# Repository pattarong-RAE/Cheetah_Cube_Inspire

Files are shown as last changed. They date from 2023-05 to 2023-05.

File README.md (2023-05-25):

# Cheetah_Cube_Inspire

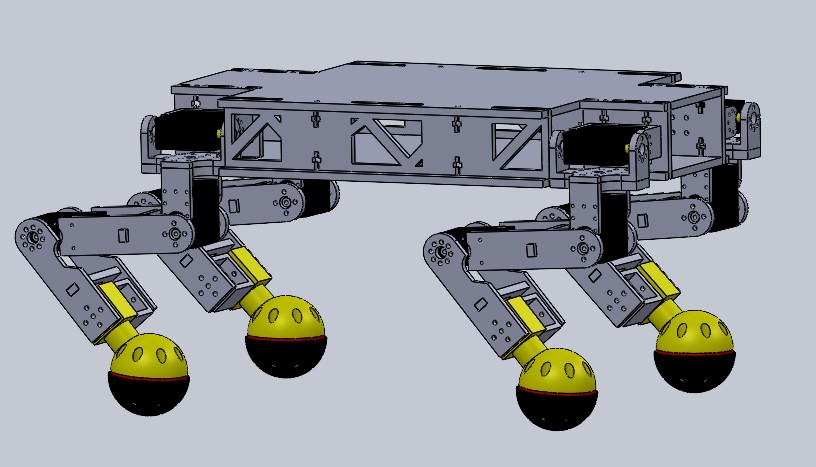
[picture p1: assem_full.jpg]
Robot


## Setup

- Install &emsp;&emsp;&emsp;&emsp;> Installation.pdf
- Setup Leg &emsp;&emsp;&nbsp;> DataRobot/datasheet/Setup_Motor.pdf

## Data

- Circuit &emsp;&emsp;&emsp;&emsp;> DataRobot/datasheet/Circuit.pdf
- Protocol &emsp;&emsp;&emsp;> DataRobot/datasheet/Protocol_send_data_Between_Ardui_and \_Python.pdf
- Set Leg robot &nbsp;&nbsp;> DataRobot/Data_set_Leg.xlsx
- Device &emsp;&emsp;&emsp;&nbsp;&nbsp;> DataRobot/DataDevice.xlsx

## Design

- Model &emsp;&emsp;&emsp;&emsp;> Model/bio
- Draw &emsp;&emsp;&emsp;&emsp;&nbsp;&nbsp;> Model/draw

## Code

- Arduino &emsp;&emsp;&emsp;&emsp;&nbsp;&nbsp;&nbsp;> Script/CheetahArduino/CheetahArduino.ino
- Python &emsp;&emsp;&emsp;&emsp;&emsp;&nbsp;> Script/main.py
- Library Python &emsp;&emsp;> Script/lib.txt
- Library Arduino &emsp;&nbsp;&nbsp;> Program/SCSServo-master

## Program

- FD-V1.9 &emsp;&emsp;&emsp;&emsp;> Program/FD-V1.9.6(20200311)
- Docklight &emsp;&emsp;&emsp;&nbsp;> Program/Docklight

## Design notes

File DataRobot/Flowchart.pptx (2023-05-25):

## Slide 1

Feedback hip , knee and load knee

Send data to computer

Get data from computer

start

NODEMCU ESP32

Set model

Control motor

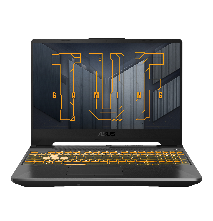
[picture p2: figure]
2021 ASUS TUF Gaming F15 FX506 | Gaming notebook | ASUS ประเทศไทย

Send data Arduino to Python

Send data Python to Arduino

Update hip and knee

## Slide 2

Update hip , knee and load

Calculate O1 , O2
Update global O1 , O2
Update time peak global

Send position hip and knee

start

Computer

Send data Arduino to Python

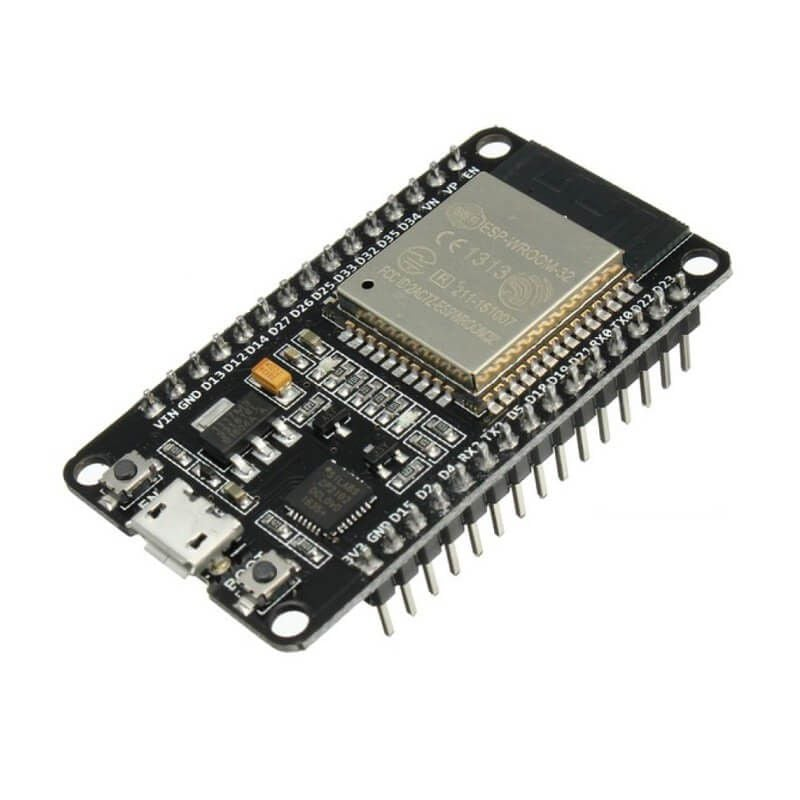
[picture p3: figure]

Send data Python to Arduino

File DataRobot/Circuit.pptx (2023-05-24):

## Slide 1

3.3 V

GND

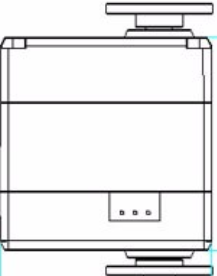
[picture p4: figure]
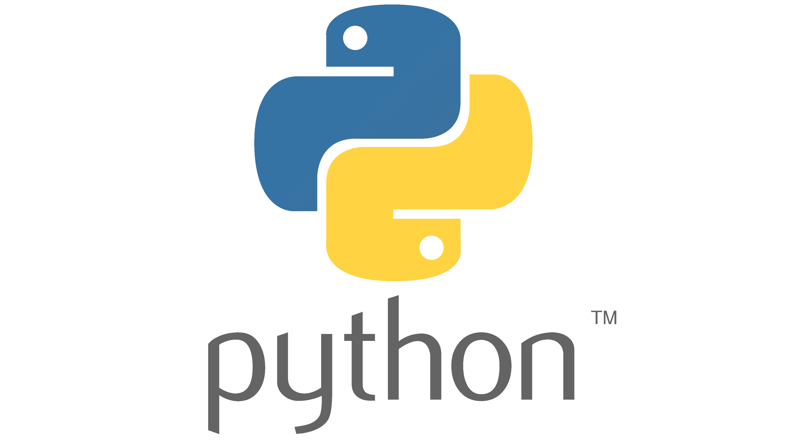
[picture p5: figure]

x12

2021 ASUS TUF Gaming F15 FX506 | Gaming notebook | ASUS ประเทศไทย
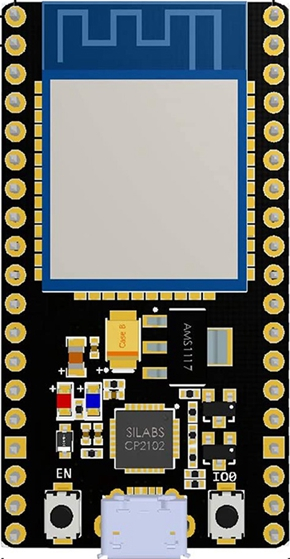
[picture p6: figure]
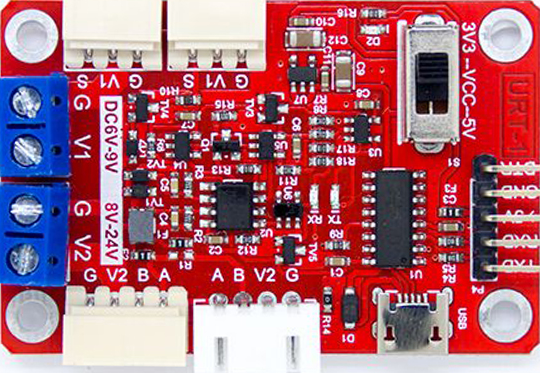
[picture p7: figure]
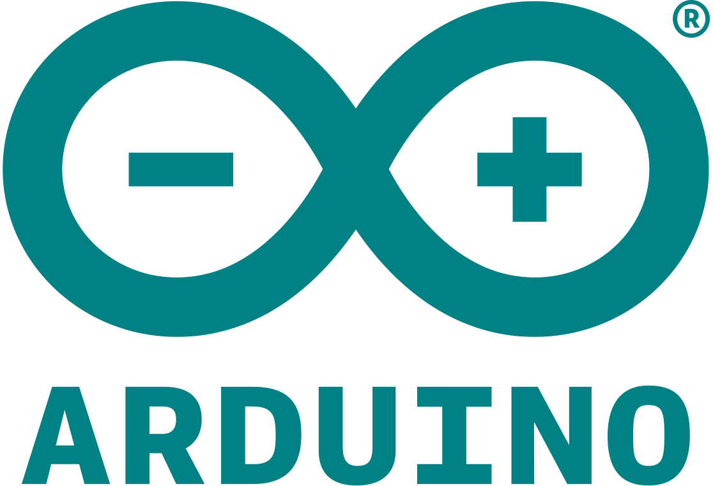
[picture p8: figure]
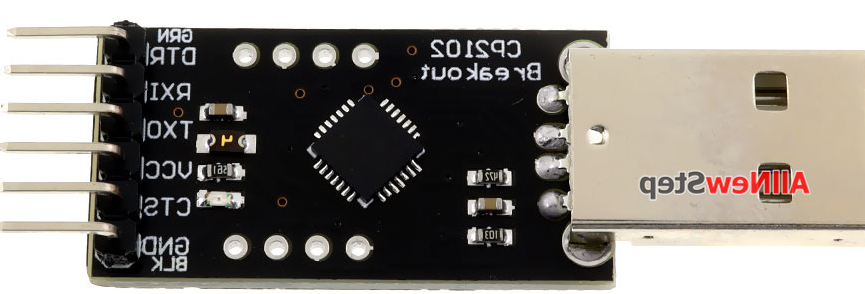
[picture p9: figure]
ตัวแปลงสัญญาณ usb ttl สำหรับ Arduino USB to UART CP2102 with DTR/CTS pinout - ArduinoAll ขาย Arduino ซื้อ Arduino อุปกรณ์ Arduino Sensor ส่งฟรี

7 V
10 A

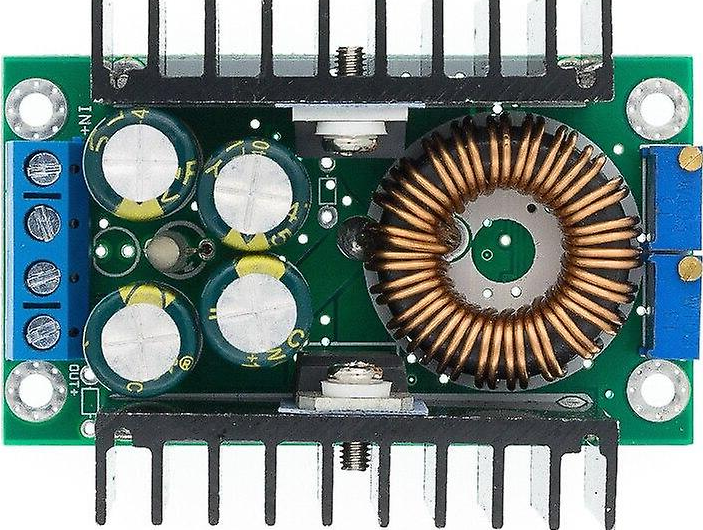
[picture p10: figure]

Micro to Usb

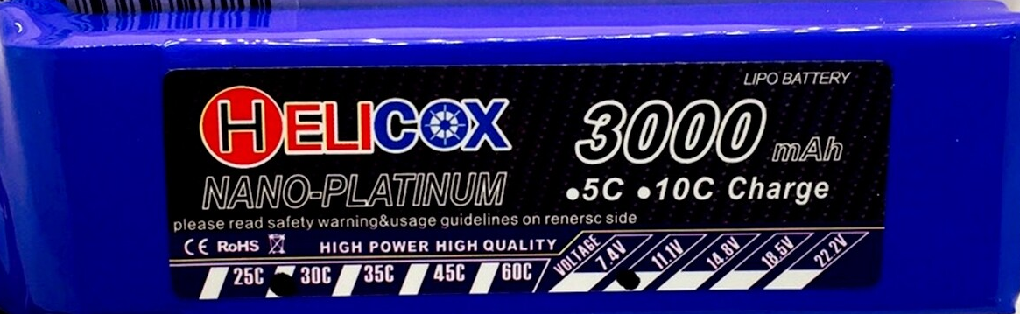
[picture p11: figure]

11.1 V

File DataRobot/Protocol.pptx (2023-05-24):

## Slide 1

0xFF

FF

FF

Name Leg | Shoulder ID | Hip ID | Knee ID
FR Forward Right | 1 | 5 | 9
BR Behind Right | 2 | 6 | 10
FL Forward Left | 3 | 7 | 11
BL Behind Left | 4 | 8 | 12

0xFF

0x19

Len

Round = 0

data

0x11

Clear data

Send data Arduino to Python

Yes

No

oxFF

oxFF

ox19

Len

FR

Position Hip

BR

FL

BL

FR

Position Knee

BR

FL

BL

FR

Load Knee

BR

FL

BL

sum

Round < Len-1

No

Check Sum

Send data Python to Arduino

Position Hip

Position Knee

Yes

oxFF

oxFF

Len

ox11

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
Round = Round+1

Copy data[ ] to command

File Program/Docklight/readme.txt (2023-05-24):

Docklight / Docklight Scripting V2.2.8

Copyright 2016 Flachmann und Heggelbacher GbR (www.fuh-edv.de)

Program Description:
Docklight is a test, analysis and simulation tool for serial communication 
protocols (RS232, RS485/422 and others). It allows you to monitor the 
communication between two serial devices or to test the serial communication
of a single device. Docklight is easy to use and runs on almost any standard 
PC using Windows 10, Windows 8, Windows 7 or Windows XP operating system.

Docklight Scripting provides an easy-to-use program language and a built-in 
editor to create and run automated test jobs. In addition to COM ports (RS232, ...), 
Docklight Scripting supports TCP, UDP, USB HID or Named Pipes.

Installation:
- Run DocklightSetup.exe (resp. DocklightScriptingSetup.exe)

Distribution:
- See the fuh_distribute_support_int.txt" file

Version History:

Docklight / Docklight Scripting V2.2.8 (11/2016)
Fixes and Improvements:
- Windows visual style and high DPI awareness. (No "blurry fonts" with display
  text size 125% or higher.)

Docklight / Docklight Scripting V2.2.4 (07/2016)

New features and functions:
- Scripting: "_auto.pts" script convention for automatic script loading & execution along with the 
  project file.
- Scripting: Extended USBHID channnel options for variable Output Report IDs and size.
- Send and Receive Sequence List have now a small lock to protect against accidental 
  sequence list reordering.
- Special educational and promotional license key scheme combining a license key and the 
  license holder's name.
- License registration dialog now allows deleting/uninstalling the license.
    
Fixes and Improvements:
- Scripting: USB HID compatibility in Windows 10 fixed. USB HID is now "Shared Access".
- Scripting: USB HID now correctly indicates when a TX / write output report did not succeed.
- Mouse wheel support in sequence lists.
- Keyboard Console now supports ESC key to send ASCII code 27 (Escape).
- Improved Checksum spec parser and added example for common LRC. "-MOD256" specifier 
  for "data + checksum = 0" style checksum.
- Fixed bug: On some serial devices with more than 4K serial buffers and high data load, 
  Docklight could crash with "Internal error 1000 in module 
  MdCommunication.printAndLogIntCommData Internal comm. processing error".
- Fixed bug: When using a certain sequence of opening, closing and re-opening the 
  Control Character Shortcuts dialog, Docklight could crash. 
- Fixed bug: RTS line corrected for Flow Control "RS485 Transceiver Control"
  and "Hardware Handshaking".
- Fixed bug: Keyboard Console line break behavior, now CR/LF (or CR only or LF only) 
  is always added correctly. 

Docklight / Docklight Scripting V2.1.10 (09/2015)

Note: 
- New V2.1 project file format for checksum support. 
  Projects without checksums are stored in the V2.0 format for compatibility. 

Fixes and Improvements: 
- Faster RTF (colored text) formatting, especially with text that contains a lot of color changes. 
- More readable and more up-to-date fonts and layout.
- Improved display overload handling, e.g. when RTF formatting still takes too long. Docklight does
  not freeze, but switch to Plain Text Mode automatically and indicate a warning. 
- Improved COM port enumeration in the Project Settings dialog: 
  Should find some rare device types that were previously omitted. Uses now SetupAPI, plus additional 
  registry readout from HKEY_LOCAL_MACHINE\HARDWARE\DEVICEMAP\SERIALCOMM. 
- Added Receive Sequence comment macros: %_N for Sequence Name, %_I for Sequence Index,
  %_X for data direction.
- Adjusted standard baud rate list, includes now 230400 baud.
- Fixed bug: For "RS485 Transceiver Control - Set RTS high while sending", XON/XOFF was enabled, too. 
- Fixed bug: Tap Pro time drift correction with Windows Time / fixed "jump to earlier time"
- Fixed bug: Tap Pro baud rates 230.4K and higher, ParityReplacementChar = 0 (ignore)
- Fixed bug: Bitwise comparison operator ('^') would not work after '#' wildcard section. 
- Fixed RTS/DTR, XON/XOFF inconsistencies: No temporary RTS/DTR glitches when switching baud rates
  or opening port. Corrected XON/XOFF when project setting and not script controlled.
- Ctrl+W (Clear Communications) works now regardless of focus
- Fixed bug: "Repeat Send" button state wrong after switching representation
- Fixed bug: Sequence lists: Delete a row, then use up/down keys - wrong line was marked
- Fixed bug: Rare crash when using Find for Communication Window
- Scripting: Changed name and extended DL.GetEnvironment() function. Added Docklight-specific keywords
  for reading Docklight project and version data.
- Scripting: Active Keyboard Console now blocks/disables script editor text box.
- Scripting: Fixed crash when starting with command line option "-r", then closing with Alt+F4. 
- Scripting: Fixed #include bug: "Script preprocessor error: Duplicate Include for same file" appeared,
  even for unique include paths. 
- Scripting: Fixed long script loading times for large scripts (> 100KB).
- Scripting: ConvertSequenceData - new "fromText" argument to convert plain text 
  to a HEX/Dec/Binary sequence string

New features and functions:
- Checksum calculation (CRC and others) for Send and Receive sequences.
- 'Standard' Docklight now includes Function Characters support (Handshake Monitoring & Control)
- 'Standard' Docklight now includes Docklight Tap Pro / 485 support
- Channel Alias setting for custom data direction labels
- Scripting: New DL.GetReceiveComments() method - chronological list of all receive sequence comments.
- Scripting: New GetCommWindowData() method - evaluate the original comm.window output in your script
- Scripting: USB HID and Named Pipes support
- Scripting: "PROXY:<tcpPort>" - TCP Server that forwards the client's connect/disconnect behavior 
- Scripting: DL.InputBox2 for a InputBox that appears on the same screen as the Docklight window
- Scripting: FileInput/FileOutput additions: .Dialog(...), .FileExists(...)
  See the \ScriptSamples\Extras\FileDialog_Example folder for an example.  

Docklight / Docklight Scripting V2.0.5 (02/2013)
New features and functions: 
- New script command "DL.SetHandshakeSignals rts As Boolean, dtr As Boolean", e.g.
  DL.SetHandshakeSignals true, false
Fixes and Improvements: 
- Improved COM port enumeration for the Project Settings dialog. Fixed freeze / very
  slow enumeration on some recent systems, additional port descriptions.
- Fixed issue with program shutdown behavior (e.g. on program close through 
  Task Manager or setup.exe). 
- In "Flow Control = Manual" you can change RTS/DTR states now without opening the 
  COM port. A "Flow Control = Manual" project now always start with RTS=low and 
  DTR = low
- DL.SetChannelSettings now allow changing baud rates and other serial parameters 
  on-the-fly, i.e. without closing the communication channel first. 
- Fixed v2.0.1 bug: Communication Filter not correctly maintained after a project
  was loaded via DL.OpenProject

Docklight / Docklight Scripting V2.0.1 (08/2012)
New features and functions: 
- Support for EZ-Tap Pro and Versa-Tap from www.stratusengineering.com
  (see also http://docklight.de/support/support_dl_faq034.htm) 
- New setting for COM communication channels: 
  Baud Rate "None" = Don't set serial communication settings (baud rate, parity ...) 
  (to avoid problems with virtual COM drivers / Embedded COM stacks that do not support this)
- New OnReceive_GetDateTime() / OnReceive_GetMilliseconds() method
- New DL.ConvertSequenceData() for processing float and integer encoded values
- New DL.SetContentsFilter() to change Communication Filter settings while channel is open
- New Function Character '^' for bitwise comparisons
- New Receive Sequence comment macros (%_L, %_T, %_C, %_A, %_H, %_D, %_B)
- New method DL.GetHandshakeSignals()
- New method DL.GetEnvironmentVariable(<environmentString>), e.g. DL.GetEnvironmentVariable("USERNAME")

Fixes and Improvements:
- Improved Receive Sequence matching: no more restrictions cursor-based matching. All possible
  matches are considered. 
- Improved non-modal "Find Sequence..." dialog. Better matching, wildcards now allowed
- New command line option '-i' for invisible background operation
- Extended OnSend_GetData() / OnReceive_GetData() syntax for returning substrings
- Fixed bug with StartLogging: "Internal error 1000 in module MdCommunication.printAndLogIntCommData"
- Fixed ghost ".exe" when closing Docklight (using Alt + F4) while logging is active
- Fixed crash in "Create Log file(s)" when providing an illegal base file path 
- Fixed bug in File->Import Sequence List..: Receive Action index was incorrectly set.
- Docklight allows now manually editing a project file in a text editor, without having 
  to maintaining the original sequence indexes. Docklight will re-index on project load 
- Digitally signed setup packages and executables (.exe, .dll)

Docklight / Docklight Scripting V1.9.21 (05/2009)
New features and functions: 
- Support for Docklight Monitoring Tap USB - Choose comm.channels TAP0 / TAP1
  (e.g.) instead of COM4 / COM5 for best monitoring accuracy better than 10 
  milliseconds
- Milliseconds timestamp resolution and improved overall timing accuracy
  (menu Tools-->Options, "Date/Time Stamps")
- Menu Tools --> Expert Options: 
  Comm. Driver Mode = External / High Priority Process
  for higher accuracy when monitoring serial COM ports
- Menu Tools --> Expert Options: Disable data forwarding in Monitoring Mode 
  for higher data throughput when monitoring serial COM ports
- Receive Sequence Function Character "!" to detect handshake signal changes
- Menu Scripting --> Customize / External Editor: 
  use a third party program editor with advanced editing features like 
  syntax highlighting
- Break Script menu/toolbar and DL.Break method: 
  interrupts script execution and shows the current line in the editor
- #include statement / include file support for scripts
 
Fixes and Improvements:
- Keyboard console state is now remembered when communication is stopped and 
  started again.
- Flow Control Support "Manual" now displays the RI (Ring Indicator) status, too
- Multiple input / output files: 
  Up to 4 FileInput objects and 4 FileOutput objects can be used simultaneously
  FileInput, FileInput2, FileInput3, FileInput4
  FileOutput, FileOutput2, FileOutput3, FileOutput4
- Show recently used network addresses in the drop down list of the 
  Project Settings dialog
- DL.AddComment Chr(7) can be used to produce a beep sound 
- You can now call user-defined Subs or Functions from inside DL_OnSend() or
  DL_OnReceive()
- CRCs with less than 7 bits now available. New predfined keyword "CRC-7" for
  7 bit CRC used with MMC / smart card applications 
- Improved performance when opening / starting large scripts
- Fixed bug: Flow control setting "RS485 Transceiver Control" would activate 
  XON/XOFF, too
- Fixed bug: DL.LoadProgramOptions "" now displays the file open dialog correctly
- Fixed bug: Keyboard console in V1.8.10 introduces new timestamp after each 
  character
- Fixed bug: Keyboard console steals focus from other applications.
- Fixed bug: Run-time error 91 could occur when Docklight is closed with logging
  still running
- Fixed problem: Docklight goes to 100% CPU load with certain (virtual) COM port
  drivers.  

Docklight / Docklight Scripting V1.8.10 (03/2008)
New features and functions: 
- HTML log file format can be customized.
- New DL.GetChannelStatus() method to determine the communication channel status
  (closed, open, waiting for TCP connection, or error).
- New DL.PlaybackLogFile() method to replay a recorded communication. 
- New DL.SaveProgramOptions() / DL.LoadProgramOptions() methods to save and load
  Docklight user options (display settings, ...)
Fixes and Improvements:
- DL.OnSend_Peek() / DL.OnReceive_Peek(): optional parameter to return the value 
  in Docklight's ASC, HEX, Decimal or Binary representation
- DL.SetChannelSettings(): Additional "dontTest" argument to suppress the open/close
  attempts for testing purposes.
- Improved multiple screen support.
- Sequence editor recognizes HEX, Decimal or Binary data in various
  formats (e.g "5A A5 0F", "5A-A5-0F", "5A/A5/F" or "5AA50F")
- Sequence Editor mode (ASCII / HEX / Decimal ...) always follows the
  selected Communications Window Mode.
- Improved sequence editor behavior when deleting a single HEX character.
- Keyboard Console allows transmitting data by pasting from clipboard (up to 
  1034 characters).
- new menu Help->Contact E-Mail Support allows sending relevant user setttings, 
  to faciliate customer support.
- Baud rates down to 1 (one) can be selected now (Note: Make sure your COM
  port device can handle such low baud rates properly.) 
- Fixed compatibility problem with Keyspan USA-19H USB adapter
- Fixed bug: FileInput.OpenFile "" now uses file open dialog correctly
- Fixed bug: Docklight Scripting now sets working directory correctly when 
  started from command line.

Docklight / Docklight Scripting V1.7.37 (06/2007)
Fixes and Improvements:
- For ASCII log files, the ASCII character code 26 is now replaced by 127.
  ASCII code 26 serves as a end-of-file mark for text files and should be 
  avoided in text files.
- Improved behavior when CR only or LF only is used for end-of-line: 
  The line break is now inserted always before a comm.direction change, a new 
  date/time stamp or a comment.
- Improved behavior when a TCP client is immediately rejected: 2 seconds idle
  time before retry.
- Fixed bug: Class definitions with private member variables caused syntax
  error. 
- Fixed bug: Docklight V1.7 now stores COM > 16 correctly

Docklight / Docklight Scripting V1.7.33 (04/2007)
New features and functions: 
- Networking: Docklight Scripting can act as TCP client, TCP server or UDP peer
- new FileInput / FileOutput objects for easy and straightforward file I/O
- new DL.CalcChecksum() method for calculating CRCs of any type
- new DL.SetChannelSettings() / DL.GetChannelSettings() methods for changing
  the communication port and settings (baud rate, ...) while running a script.
- new DL.Quit() command to stop script execution
- new DL.GetDocklightTimeStamp() method to return a Docklight-style time stamp

Fixes and Improvements:
- COM1 to COM256 can be selected.
- Project Settings dialog shows available COM ports in dropdown list.
- Timing acurracy in monitoring mode improved.
- Improved transmit and receive buffering, less COM buffer overflows
  on high-speed connections.
- Monitoring mode additionally transmits the received data on the 
  opposite communication port (data forwarding).
- Communications display now buffers up to 128.000 characters.
- Log file buffers are now flushed after 1 seconds of inactivity.
- "RS485 Transceiver Control" now uses Windows RTS_CONTROL_TOGGLE mode with
  improved timing (Windows NT/2000/XP/Vista only)
- Parity Error Character: "(ignore)" for reading characters with wrong parity bit
- The "Edit Send/Receive Sequence" dialogs show the current cursor position 
  and support cursor keys (Page Up/Down, Cursor Up/Down, Home/End).
- Minimum time for "Send Sequence periodically" now 0.01 sec (before: 0.1 sec)
- Additional operations on sequence lists: Import from a project file, 
  swap receive and send sequence lists.
- Improved behavior for large sequence lists (> 100 sequences).
- Fixed rare crash in Sequence Editor after copying & pasting a sequence 
  using Ctrl+C and Ctrl+V.
- DL.UploadFile() supports raw binary data tranfer mode ("R").
- DL.UploadFile(), DL.StartLogging(), DL.OpenProject() show a file dialog 
  if an empty file path argument is passed.
- DL.StartLogging() closes a previously opened log file automatically, 
  instead of returning an error.
- DL.AddComment with additional formatting options.
- DL.ResetReceiveCounter now additionally resets the Receive Sequence detection
  algorithm, allowing easier resynch in complex protocols.
- Additional "!" function character arguments for temporarily changing the parity 
  settings within one Send Sequence. 
- Receive Sequence supports "&" Delay function character to detect pauses.
- DL.StartLogging uses current script directory by default (same behavior as
  DL.OpenProject or DL.UploadFile).
  
Docklight V1.6.23 / Docklight Scripting V1.6.23 (01/2007)
Fixes and Improvements:
- HTML help instead of Winhelp to prepare Docklight for Windows Vista
- Window size correctly remembered after closing Docklight, even when maximized.
- Font sizes < 10 now allowed (with additional warning) 
- Control characters except CR/LF can be completely suppressed in ASCII display
10:16 02.04.2007- Baud rates up to 9.999.999 Baud can be entered (NOTE: This does not mean
  Docklight can really process any kind of data at that speed.) 
- Fixed bug: A "CR only" produces an additional line break in HEX, Decimal and 
  Binary display
- Fixed bug: The keyboard console tool always sets the RTS line to high when 
  typing characters
- Fixed bug: The DCD line status is not displayed
- Fixed bug in Docklight Scripting: 
  UploadFile() does not send data if the script contains a DL_OnSend() procedure
- Fixed bug in Docklight Scripting: 
  RS485 Tranceiver Control does not reset RTS while a script is executed
- Fixed bug in Docklight Scripting: 
  BREAK state introduces additional spaces in HEX, Decimal and Binary display

Docklight V1.6.8 / Docklight Scripting V1.6.8 (04/2005)
Fixes and Improvements:
- Flow control setting "RS485 Transceiver Control" is now correctly applied for
  the Keyboard Console tool.
- F12 key brings up the notepad window, even if minimized

Docklight V1.6.7 / Docklight Scripting V1.6.7 (03/2005)
New features and functions: 
- "Communication Filter" to hide the original serial data of one or both 
  communication channels
- Notepad (F12 key) for project documentation
- "Drag and Drop" support for project files and scripts
- Docklight Scripting: new method "UploadFile" for file transfer
- Docklight Scripting: new special function characters in Send or 
  Receive Sequences (set/reset handshake signals, add delay between characters, 
  send or detect a "break" state)
Fixes and Improvements:
- Keyboard Shortcuts for ASCII code > 126
- DEL key for Send/Receive Sequence lists
- Docklight Scripting: Increased maximum script size (510KB instead of 64KB)
- Inreased Docklight send/receive queue size to allow character-by-character 
  processing using DL_OnReceive()
- Extended documentation and sample scripts to demonstrate Docklight Scripting's 
  data analysis and manipulation capabilities.
- Fixed bug: Docklight crashes when a USB-to-RS232 device is removed while 
  communication is running. 
- Fixed problem: When using Option "Flow Control: RS485 transceiver control",
  the RTS line is reset too early, especially when the standard 16 byte fifo 
  transmit buffer of the UART is enabled.
- Fixed bug: Missing characters in ASCII window / Formatted Text Output mode,
  when characters are received one-by-one and a single <CR> is used for end-of-line

Docklight Scripting V1.5.2 (09/2004)
New features and functions:
- Extended syntax for the DL.SendSequence command to allow hex, decimal or binary
  Send Sequence parameters or sending custom data sequences.
- DL_OnSend() function to support automatic checksum calculations
- DL_OnReceive() function to support automatic evaluation of the received data,
  including analysing the received wildcard data
Fixes:
- Fixed bug: The DL.OpenProject command did not close the communication

Docklight V1.4.14 / Docklight Scripting V1.4.14  (06/2004)
Fixes:
- Fixed bug: Missing line breaks on Windows 98
- Fixed bug: "Clear Communication Window" does not delete the entire contents of
  all four commmunications window representations (ASCII/HEX/Decimal/Binary)

Docklight V1.4.12 / Docklight Scripting V1.4.12  (05/2004)
New features and functions:
- New Docklight edition "Scripting" with built-in script editor for automated testing.
  Available as an upgrade for Docklight standard users. 
Fixes & Improvements:
- Non-standard baud rates can be used: Type any integer number between 110 and 999999
  in the corresponding dialog box. If the chosen rate is actually applied, depends on 
  the serial UART you are using. Non-standard baud rates may not work correctly when 
  "Flow Control" options are used.
- New Mode "Flow Control: Hardware Handshaking - RTS/CTS (Single Byte Mode):
  A sequence is placed byte-by-byte into the transmit buffer and CTS is checked before 
  each new character.
- New mode "Flow Control: RTS high while sending". This is to support RS485
  converters and related applications where the transceiver requires the PCs RTS signal
  to enable/disable the transmission.
- Improved communication processing and timing accuracy, which makes the "TweakComm" 
  utility provided to some users obsolete.
- ASCII Communication Window: Uniform behavior for different end-of-line standards:
  CR only, CR+LF, LF+CR

V1.3.38 (01/2004)
Fixes:
- Fixed bug: receive sequence detection ignores incoming sequence, 
  if immediately before the sequence a few characters have already been 
  considered as a part of this sequence.   
  See http://www.docklight.de/troubleshooting_en.htm for details.
- Fixed bug: edit sequence dialog crashes when marking a sequence, then 
  moving to the empty sequence at the end of the list (Index ">" button) and
  pasting into the empty sequence.
- Fixed bug: crash when trying to paste a very large document (> 32K) from clipboard.

V1.3 (11/2003)
New features and functions:
- Powerful clipboard support within the sequence lists and the sequence 
  editor: cut, copy & paste entire sequences or parts of it. Copy & paste 
  sequence data from external applications (MS Word, Notepad).
- Wildcard support for send sequences, receive sequences and find function
- New receive sequence actions: insert time stamp, stop communication
- New time stamp options: pause detection, e.g. for RS485 monitoring.
- Keyboard console: keyboard input is directly sent to the COM port.
- New Project settings: optional flow control support, 
  manual RTS/DTR control, hardware handshaking, 
  software handshaking (XON/XOFF).
Fixes & Improvements:
- Fixed bug when printing on HP Laserjet 5M
- Improved sequence list management (reordering, keyboard support)
- Improved find function (ignores date/time stamps and additional comments
  in HEX, decimal and binary mode) 
   
V1.2 (02/2003)
New features and functions:
- Improved performance, especially when monitoring transmissions 
  with a high amount of data
- Time stamps with 1/100s precision
- New display options to further increase processing speed
- New snapshot function to catch a very rare sequence within the protocol data
  plus the preceding and trailing communication
- New demo project and additional documentation for getting started
Fixes:
- Now works on any Windows language edition, especially Asian editions or 
  others using DBCS (double byte character set) 
- Fixed bug when using sequence names which include a comma (",")

V1.1 (09/2002)
New features and functions:
- Creating log files in HTML format
- Communication settings are now stored as project data
- Improved parity error handling
- Disabling the communication window while logging possible (e.g. while 
  monitoring high-speed communication) 
- Revised and streamlined user interface
Fixes:
- 4800 Baud now available in the communication settings dialog

V1.0 (04/2002)
First release

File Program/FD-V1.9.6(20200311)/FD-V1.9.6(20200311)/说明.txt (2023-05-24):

修正SM40BL(固件版本：2.43) 位置校正参数方向位(bit15修正为bit11)
较正范围为-2047,2047

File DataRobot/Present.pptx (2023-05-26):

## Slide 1

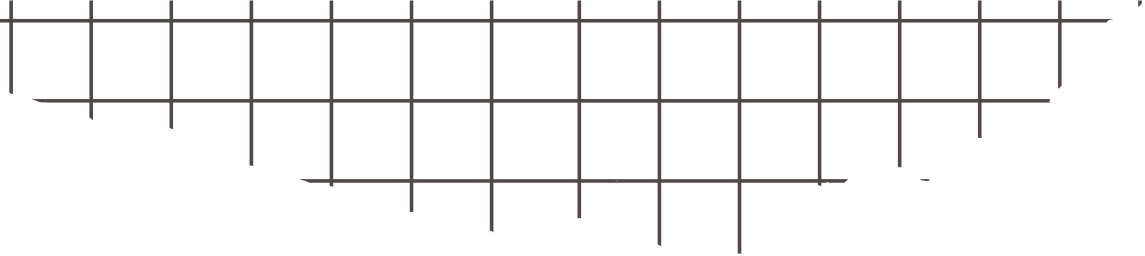
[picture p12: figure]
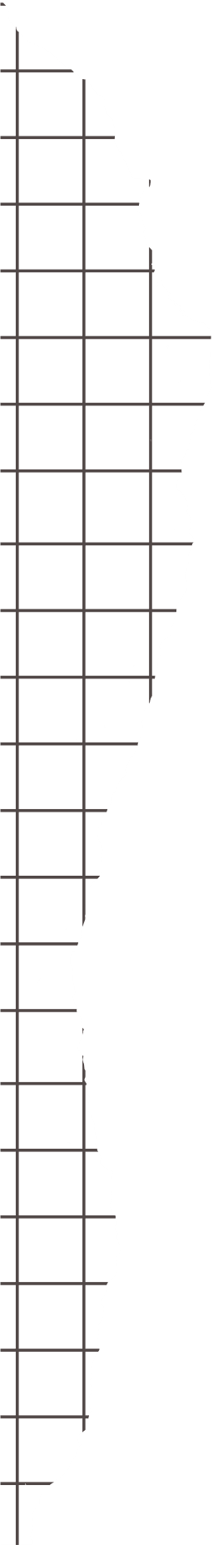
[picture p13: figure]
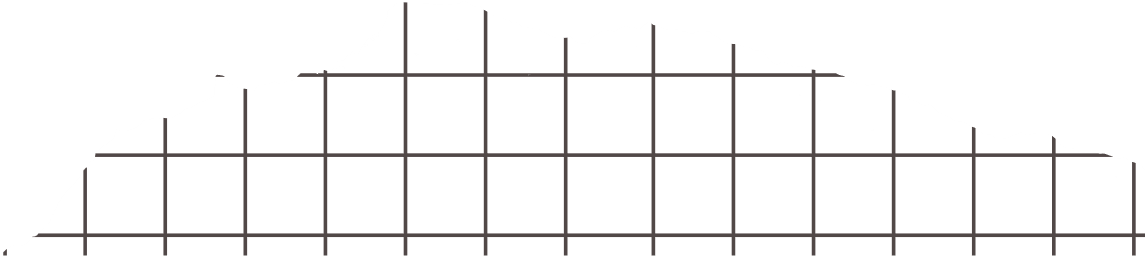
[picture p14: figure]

Cheetah

ROBOT

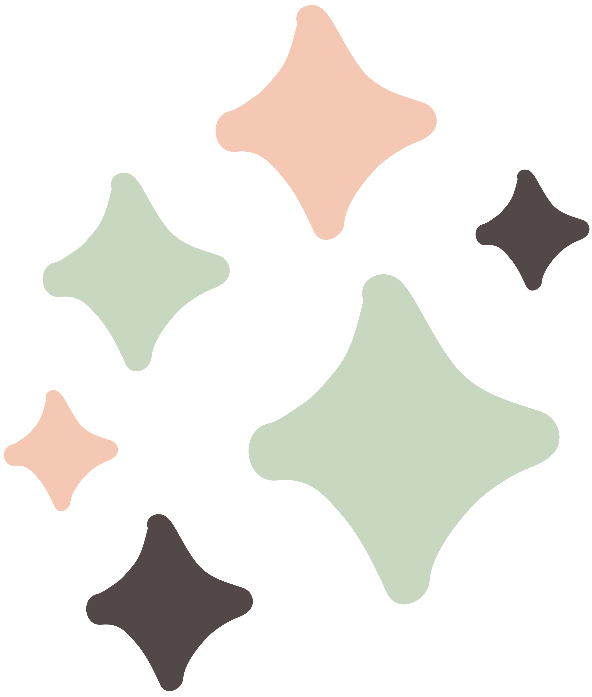
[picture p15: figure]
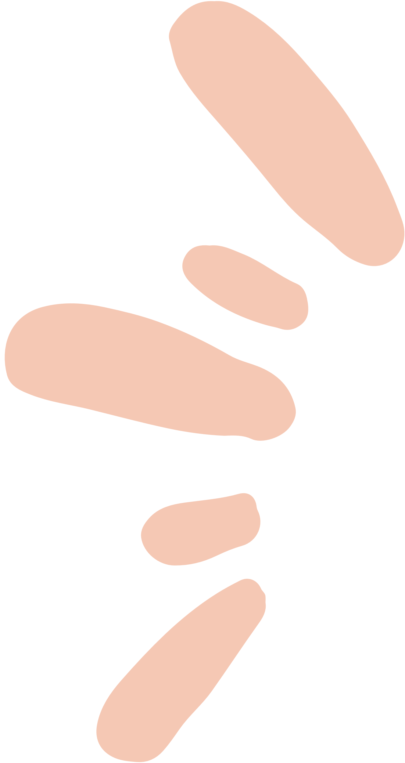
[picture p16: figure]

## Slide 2

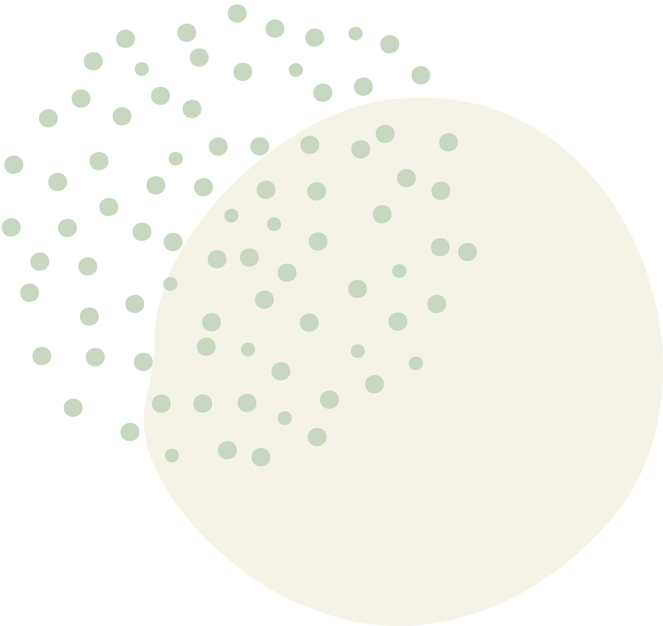
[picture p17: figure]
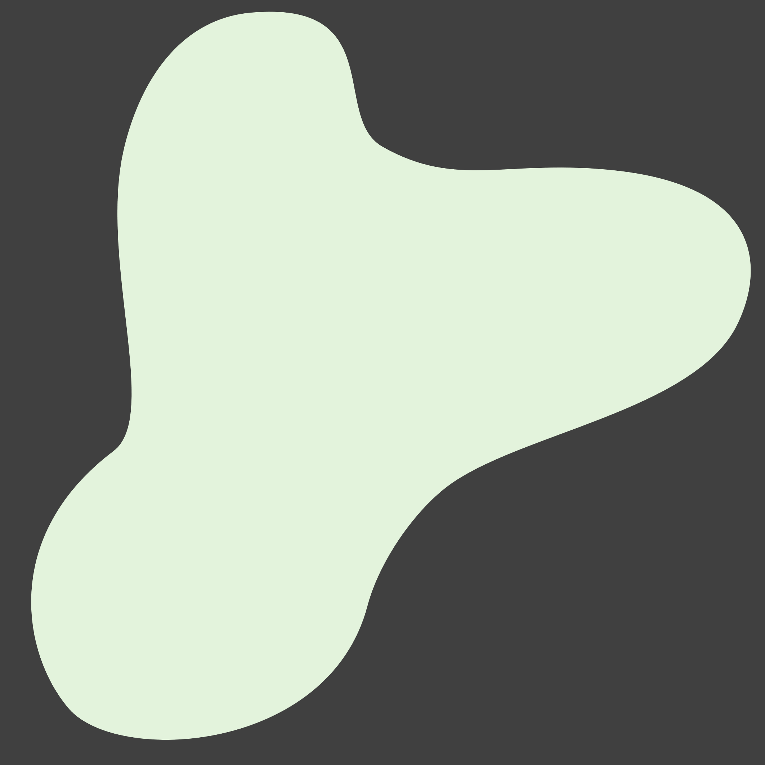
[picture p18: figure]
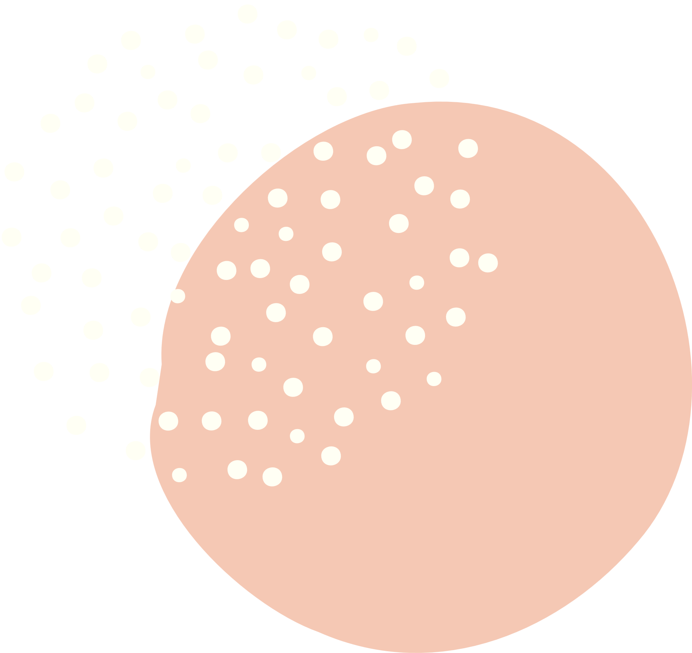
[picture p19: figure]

Parameter

-Basic rhythmic pattern generation
W = 0.2 , 1.4
-Adaptive CPG phase modulation
As = 0.99 , Af = 0.57 , Bs = 0.0002 , Bf = 0.002 , A = 0.9 , P = 0.99
-Adaptive neural communication
l and k = 1,2,3,4

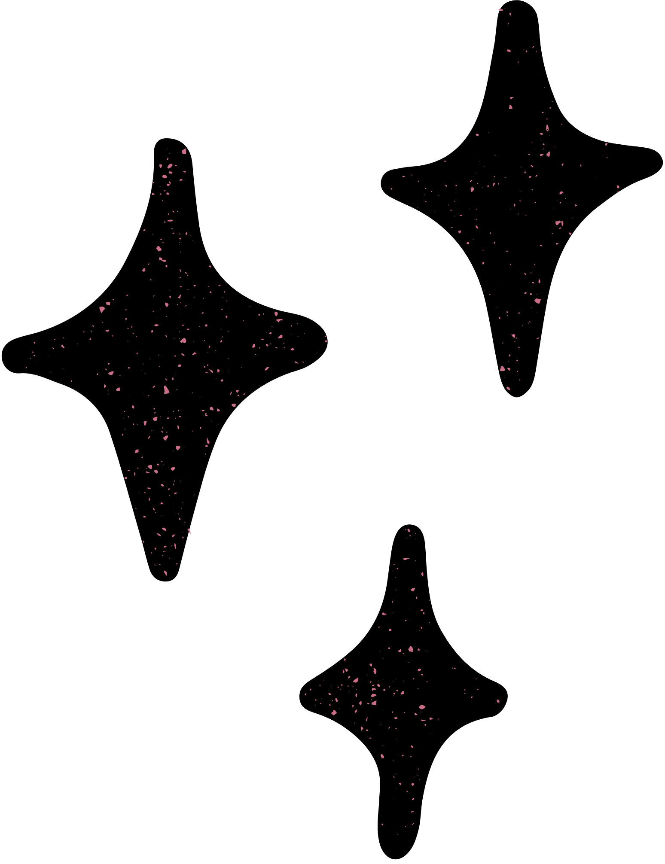
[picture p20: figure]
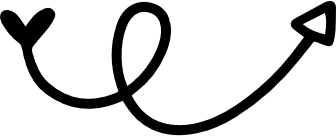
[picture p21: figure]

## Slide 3

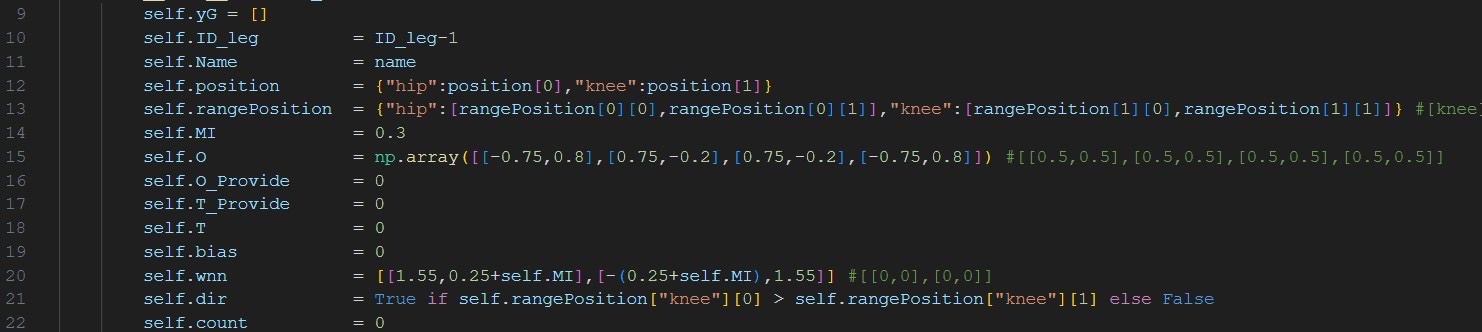
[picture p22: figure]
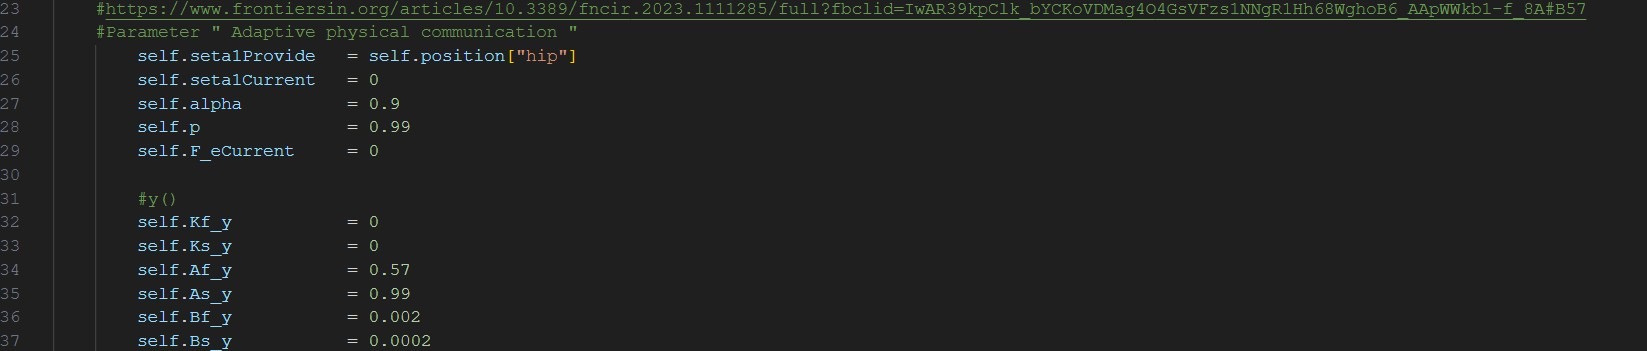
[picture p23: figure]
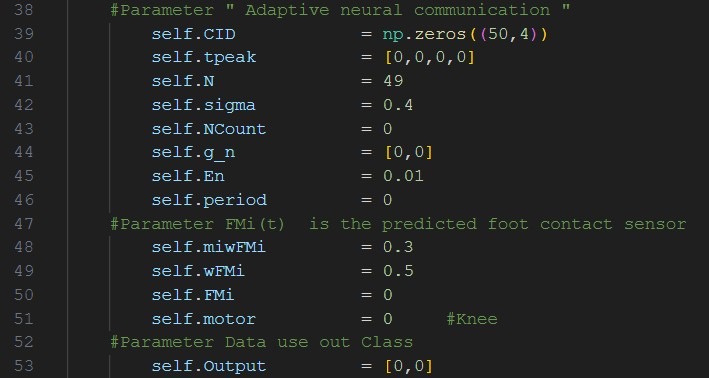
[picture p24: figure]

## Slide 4

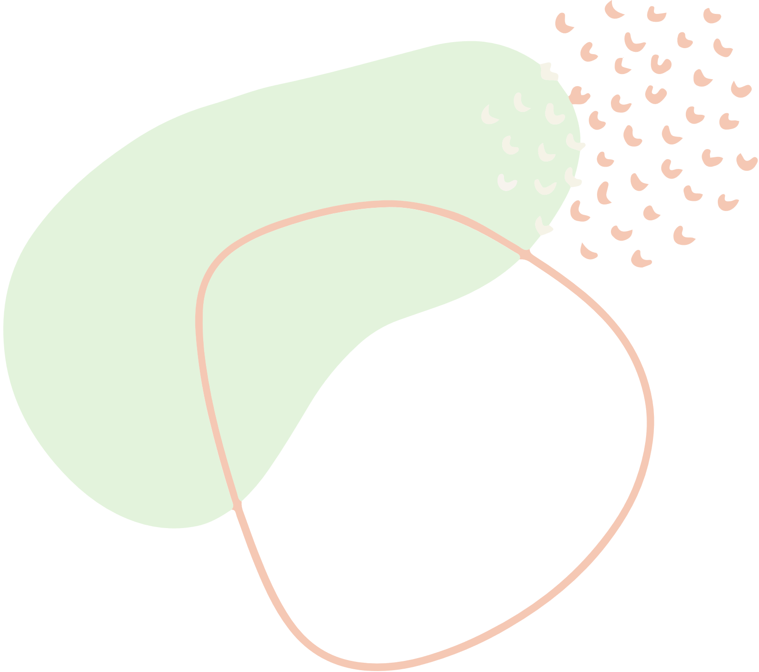
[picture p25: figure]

Flowchart


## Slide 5

เริ่มต้นการทำงาน

ปรับค่า Parameter N


วิธีการหาค่า Parameter

เริ่มต้นเราจะทำการปรับค่าพารามิเตอร์ที่ N หากสัญญาณคลื่นที่ออกมาแย่กว่าที่คาดไว้เราจะทำการปรับค่าพารามิเตอร์ที่ N ใหม่ หากสัญญาณคลื่นไม่แย่เราจะทำการปรับค่าพารามิเตอร์สุดท้ายคือพารามิเตอร์ที่ N-1 และสิ้นสุดการทำงาน หากค่าพารามิเตอร์สุดท้ายแย่จะทำการปรับค่าพารามิเตอร์ที่ N+1

ปรับค่า Parameter N+1

No

สัญญาณ O1,O2 แย่หรือไม่

ปรับค่า Parameter N-1

สิ้นสุดการทำงาน

Yes

No

Yes

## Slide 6

ทดสอบการทำงาน


ทดสอบการทำงานของ Adaptive neural communication โดยการหยุด
สัญญาณขา 1 ใน 4
เป็นเวลา n วินาทีและดูผลลัพธ์ของ output ว่าขายังทำงานอย่างไร


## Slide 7


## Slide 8

ข้อมูลเพิ่มเติม


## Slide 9

Thank You

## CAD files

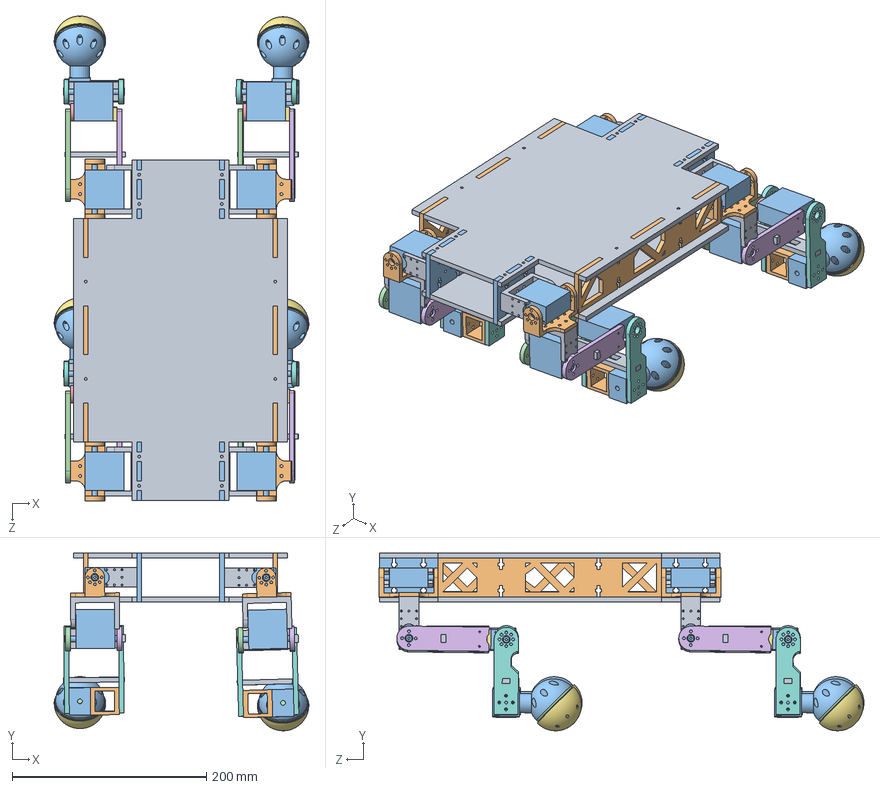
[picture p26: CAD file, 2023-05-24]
Model/bio/ASSEM/full Assem1.SLDASM
262.0 x 182.7 x 498.9 mm
servo x 12
leg top x 4
oox leg x 4
leg top righttt_edit x 4
oox leg right_edit x 4
leg min_edit x 4
oox servo x 8
Support_Foot_con x 4
foot x 4
midFootSLDPRT x 4
footRingPlate x 4
footButtonPlate x 4
wheel x 4
leg min righttt_edit x 4
sevo smail 2 x 8
servo long x 4
spacer_xxx x 4

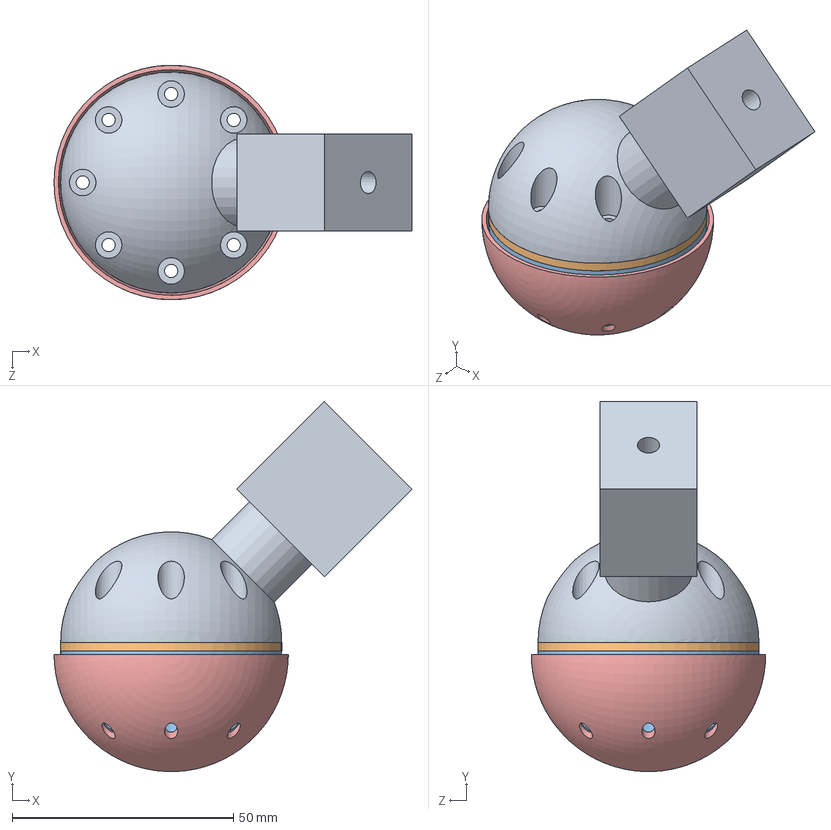
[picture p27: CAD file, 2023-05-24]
Model/bio/foot and body/Foot.SLDASM
80.9 x 83.7 x 53.0 mm
foot
midFootSLDPRT
footRingPlate
footButtonPlate
wheel

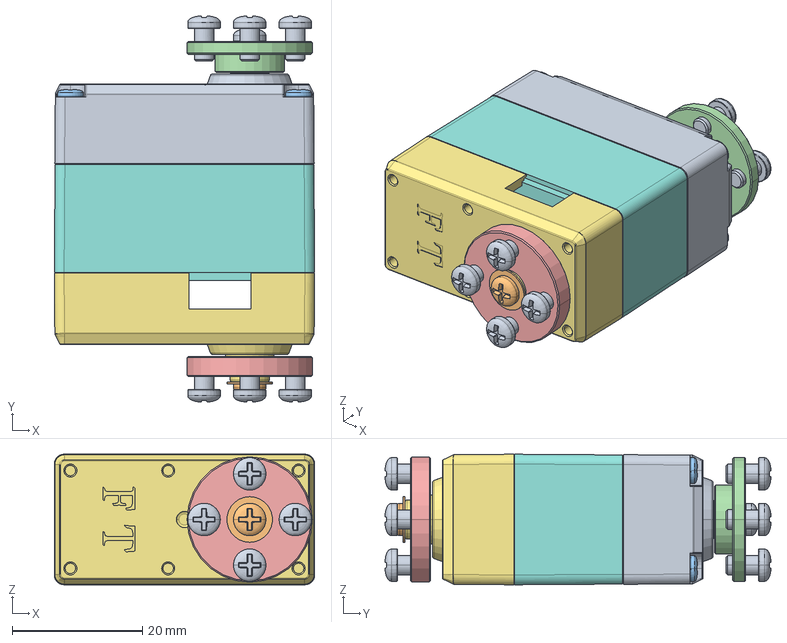
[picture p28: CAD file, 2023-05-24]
Program/SCS15（OK）/scs15_asm15kg20160222_asm.stp
39.9 x 59.2 x 20.0 mm
MSBR-20
MSBR-19
MSBR-18
MSBR-17
MSBR-16
MSBR-15
MSBR-14
MSBR-13
MSBR-12
MSBR-11
MSBR-10
MSBR-9
MSBR-8
MSBR-7
MSBR-6
MSBR-5
MSBR-4
MSBR-3
MSBR-2
MSBR-1

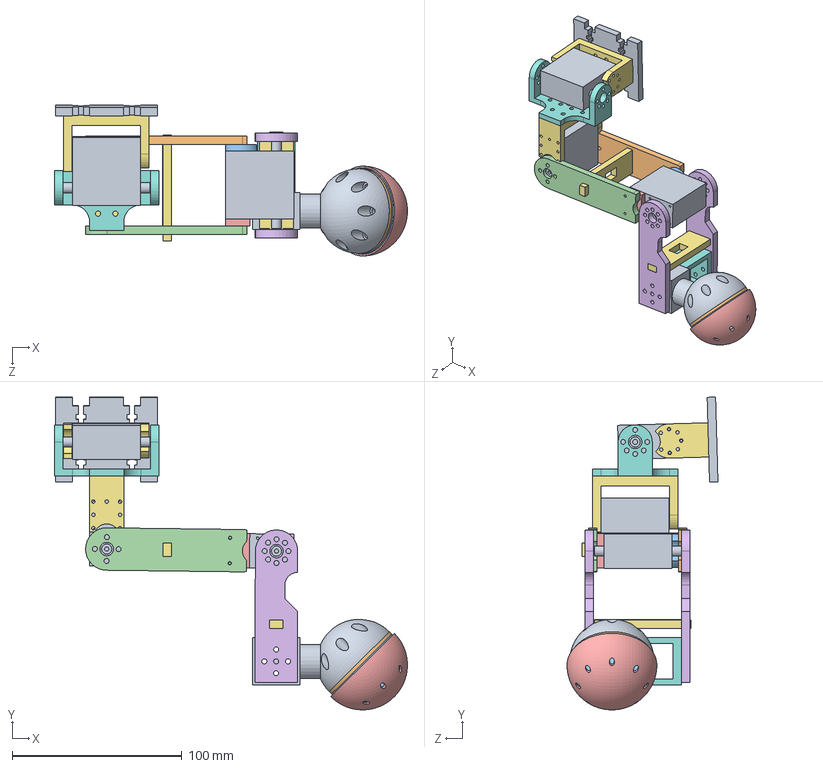
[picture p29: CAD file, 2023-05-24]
Model/bio/ASSEM/leg.full Assem1.SLDASM
208.2 x 184.5 x 89.0 mm
servo x 3
leg top
oox leg
leg top righttt_edit
oox leg right_edit
leg min_edit
oox servo x 2
Support_Foot_con
foot
midFootSLDPRT
footRingPlate
footButtonPlate
wheel
leg min righttt_edit
sevo smail 2 x 2
servo long
spacer_xxx

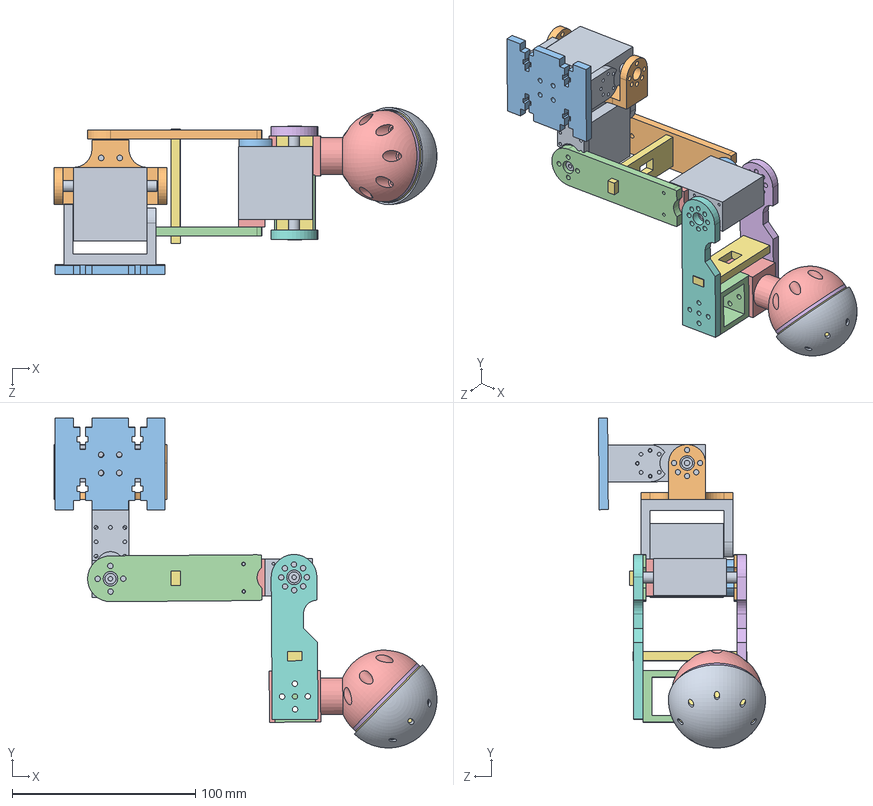
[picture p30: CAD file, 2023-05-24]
Model/bio/ASSEM/leg.full Assem2.SLDASM
208.9 x 180.0 x 91.1 mm
servo x 3
leg top
oox leg
leg top righttt_edit
oox leg right_edit
leg min_edit
oox servo x 2
leg min righttt_edit
sevo smail 2 x 2
servo long
spacer_xxx
Support_Foot_con
foot
midFootSLDPRT
footRingPlate
footButtonPlate
wheel

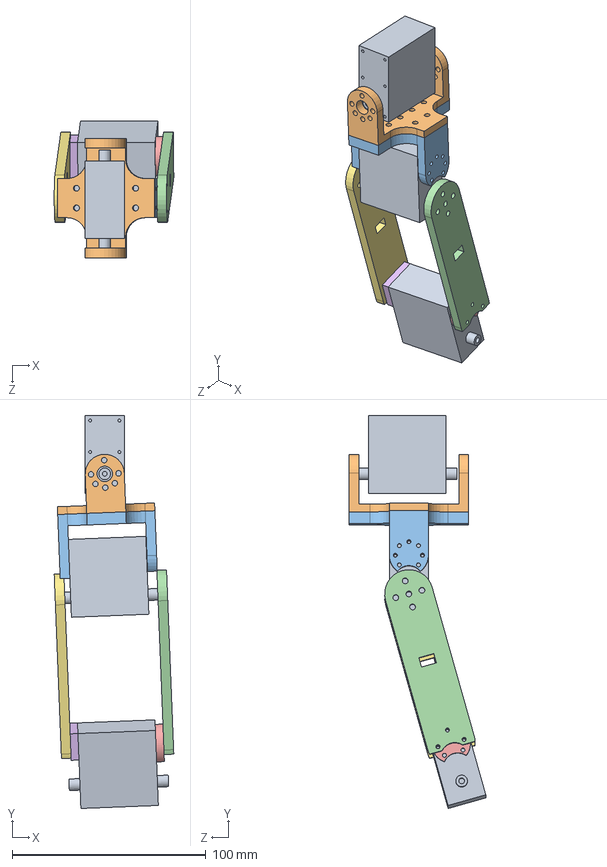
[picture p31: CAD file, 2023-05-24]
Model/bio/testassem.SLDASM
61.7 x 202.7 x 70.5 mm
servo x 3
servo long
sevo smail
leg top
oox leg
oox leg right_edit
leg top righttt_edit

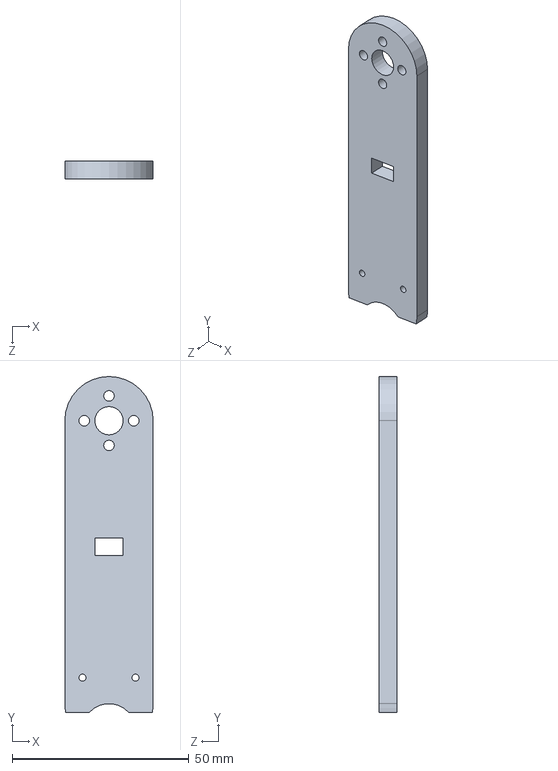
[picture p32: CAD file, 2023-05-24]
Model/bio/leg top righttt_edit.SLDPRT
25.0 x 95.0 x 5.00 mm

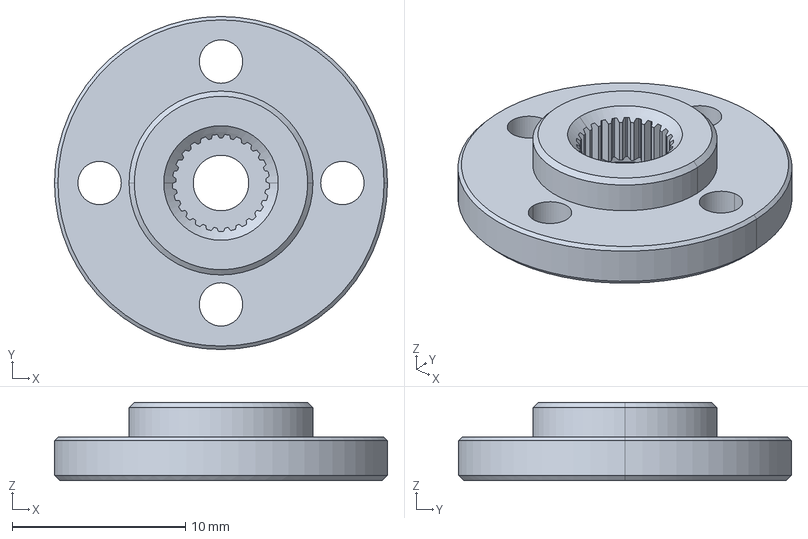
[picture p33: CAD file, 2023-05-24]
Program/SCS15（OK）/配套金属舵盘/fk-ap-019-25t.stp
19.2 x 19.2 x 4.50 mm

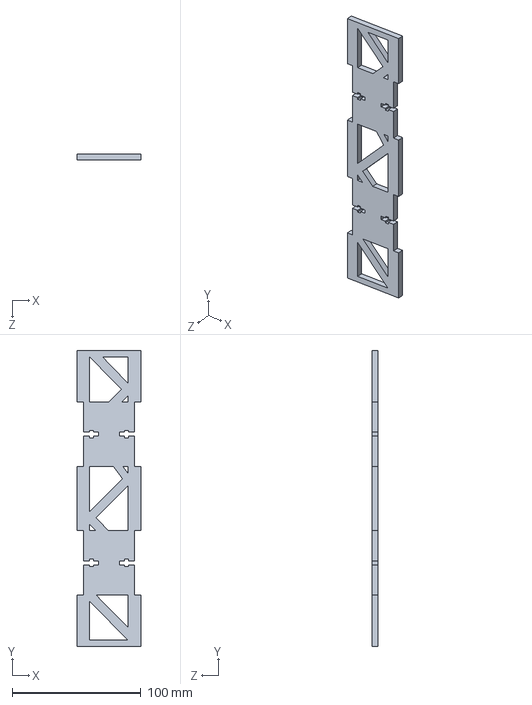
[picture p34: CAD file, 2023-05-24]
Model/bio/foot and body/Part1.2.1.SLDPRT
50.0 x 230.0 x 5.00 mm

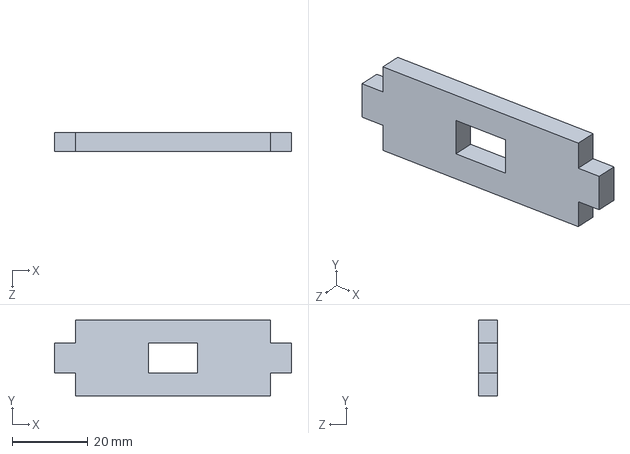
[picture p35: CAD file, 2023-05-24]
Model/bio/oox servo.SLDPRT
62.4 x 20.0 x 5.00 mm

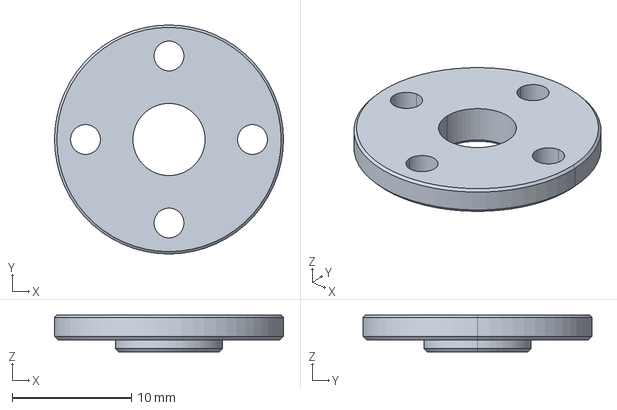
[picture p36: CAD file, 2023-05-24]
Program/SCS15（OK）/配套金属舵盘/wj-dp00-0002-fk-ap-020.stp
19.2 x 19.2 x 3.10 mm

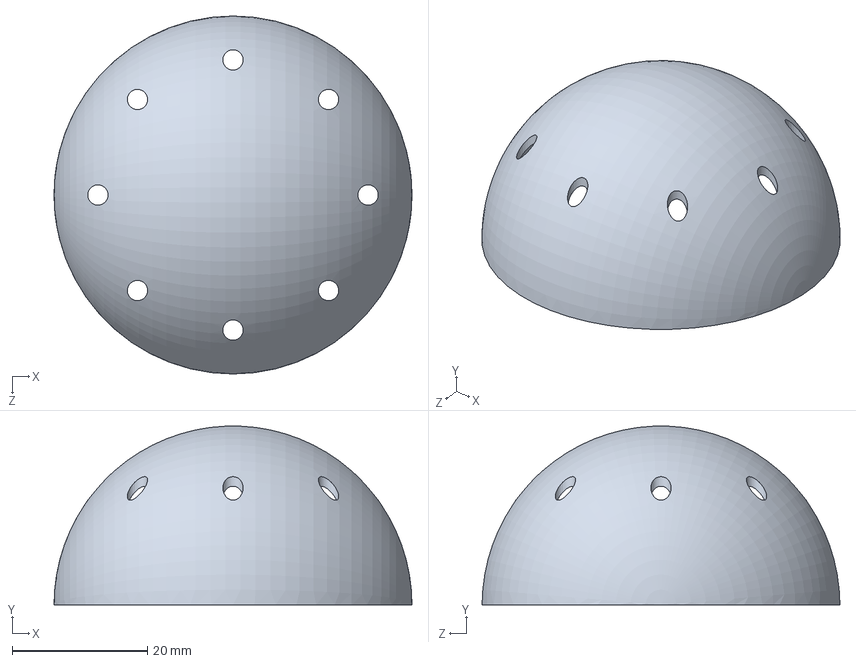
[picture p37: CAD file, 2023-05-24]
Model/bio/foot and body/wheel.SLDPRT
53.0 x 26.5 x 53.0 mm

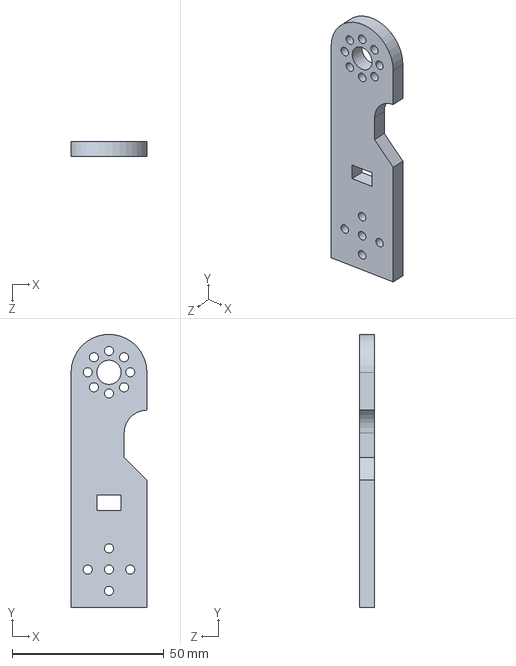
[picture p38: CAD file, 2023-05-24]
Model/bio/leg min righttt_edit.SLDPRT
25.0 x 89.9 x 5.00 mm

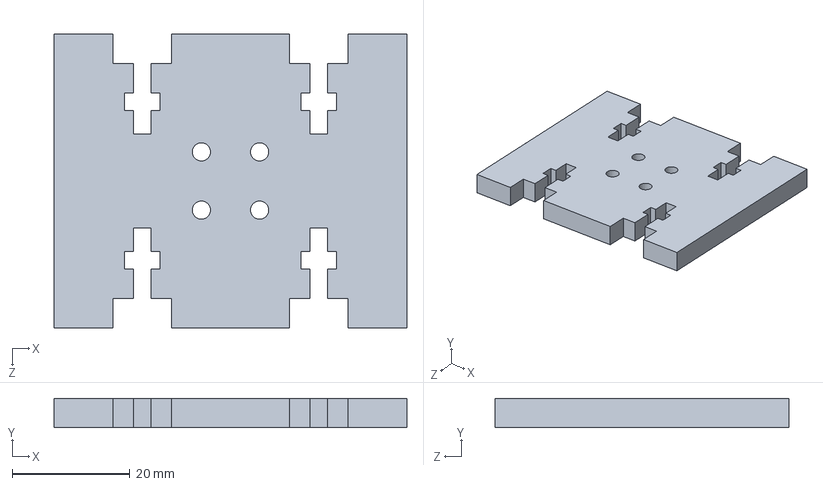
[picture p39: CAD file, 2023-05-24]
Model/bio/foot and body/spacer_xxx.SLDPRT
60.0 x 5.00 x 50.0 mm

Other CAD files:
Program/SCS15（OK）/25T size.dwg
Program/SCS15（OK）/SCS15长短U支架.dwg
Program/SCS15（OK）/配套金属舵盘/fk-ap0-19-25t-20190320.dwg
Model/bio/oox foot.SLDPRT
Model/bio/foot and body/Foot (1).SLDASM
Model/bio/foot and body/Part1.SLDPRT
Model/bio/foot and body/Support_Foot_con.SLDPRT
Model/bio/foot and body/foot.sldprt
Model/bio/foot and body/footButtonPlate.SLDPRT
Model/bio/foot and body/footRingPlate.SLDPRT
Model/bio/foot and body/midFootSLDPRT.sldprt
Model/bio/leg min_edit.SLDPRT
Model/bio/leg top.SLDPRT
Model/bio/oox leg right_edit.SLDPRT
Model/bio/oox leg.SLDPRT
Model/bio/servo long.SLDPRT
Model/bio/servo.SLDPRT
Model/bio/sevo smail 2.SLDPRT
Model/bio/sevo smail.SLDPRT
Model/draw/leg min righttt_edit.SLDDRW
Model/draw/leg min_edit.SLDDRW
Model/draw/leg top righttt_edit.SLDDRW
Model/draw/leg top.SLDDRW
Model/draw/oox leg right_edit.SLDDRW
Model/draw/oox leg.SLDDRW
Model/draw/oox servo.SLDDRW
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

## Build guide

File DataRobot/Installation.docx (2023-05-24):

Installation

1.download folder in git hub

git clone https://github.com/pattarong-RAE/Cheetah_Cube_Inspire.git

cd ./Cheetah_Cube_Inspire

2.install library and setup env with python

mkdir ./Python_code

python -m venv ./Python_code

./Python_code/Script/activate

pip install -r ./Python_code /Script/lib.txt

cd ./Script

3.Burn board NODEMCU ESP32 file name “CheetahArduino.ino”

4.Run control robot this file “main.py”

python ./main.py

run in folder terminal

git clone https://github.com/pattarong-RAE/Cheetah_Cube_Inspire.git

cd ./Cheetah_Cube_Inspire

mkdir ./Python_code

python -m venv ./Python_code

./Python_code/Script/activate

pip install -r ./Python_code /Script/lib.txt

cd ./Script

python ./main.py

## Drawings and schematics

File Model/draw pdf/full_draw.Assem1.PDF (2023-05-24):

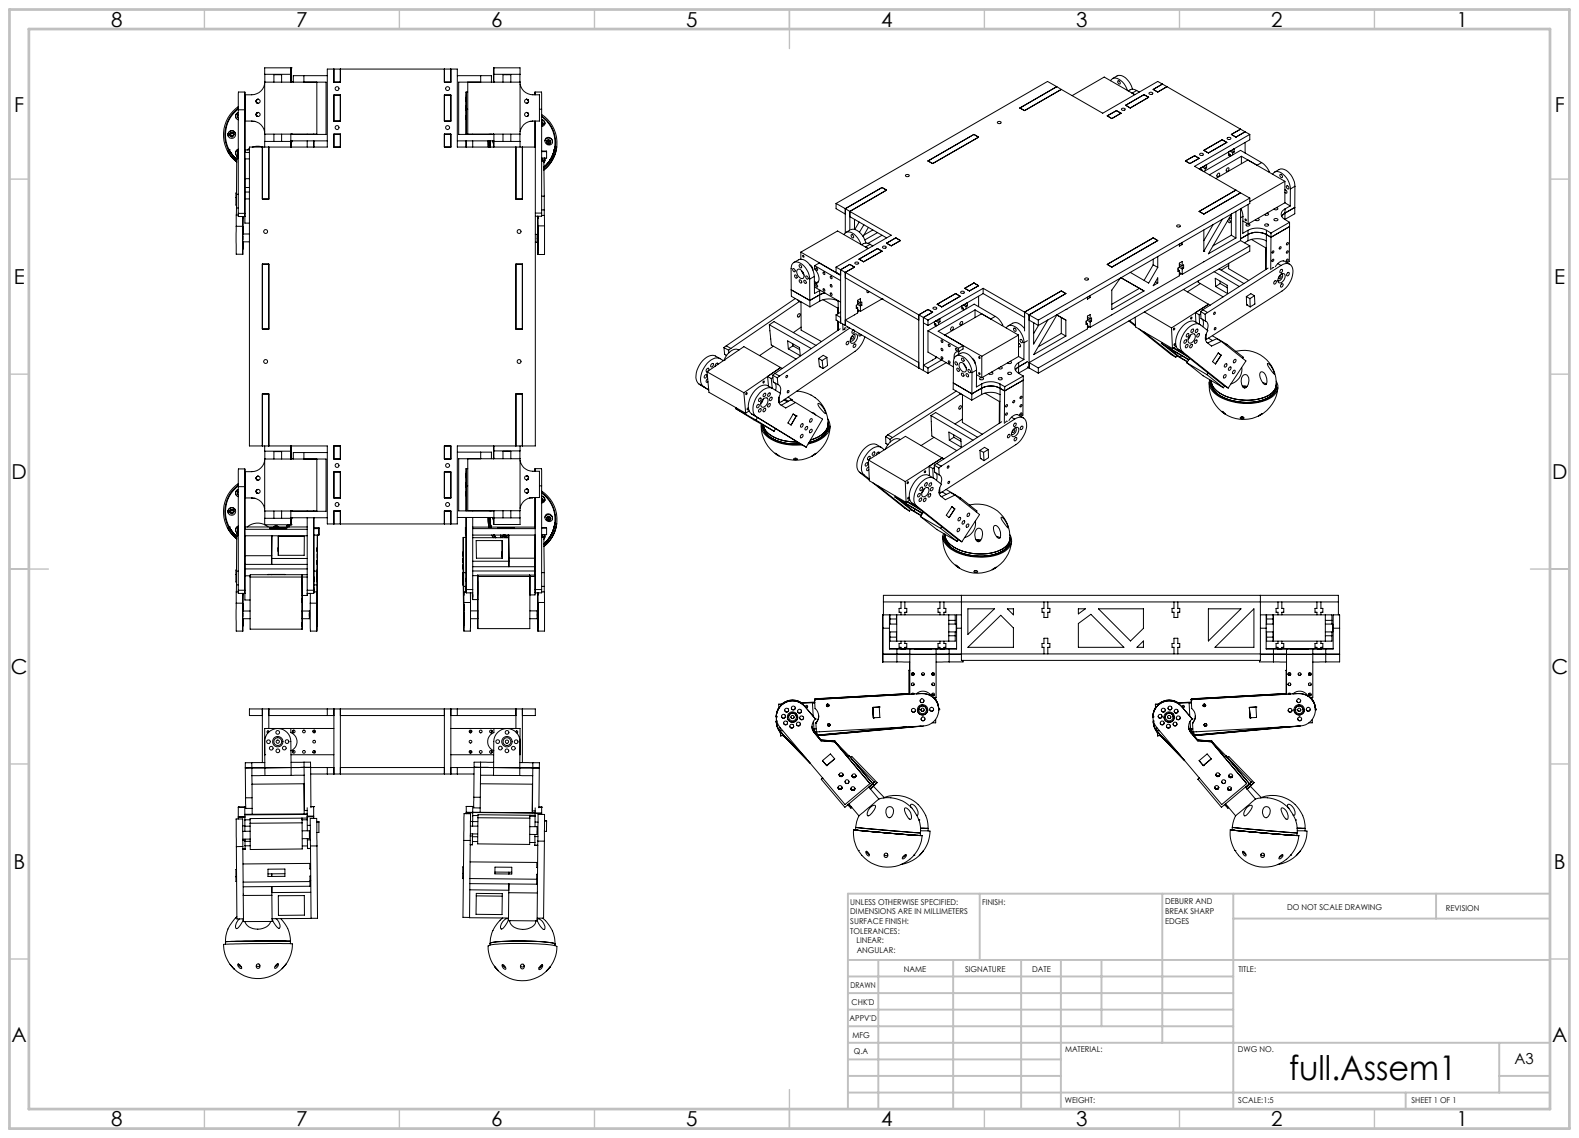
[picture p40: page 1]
FINISH:; DEBURR AND; BREAK SHARP; DO NOT SCALE DRAWING; REVISION; SCALE:1:5; SHEET 1 OF 1

UNLESS OTHERWISE SPECIFIED:
DIMENSIONS ARE IN MILLIMETERS
SURFACE FINISH:
TOLERANCES:
LINEAR:
ANGULAR:

NAME | SIGNATURE | DATE | | | | TITLE:

DRAWN
CHK'D
APPV'D
MFG
Q.A | | | | MATERIAL: | DWG NO. full.Assem1 | A3

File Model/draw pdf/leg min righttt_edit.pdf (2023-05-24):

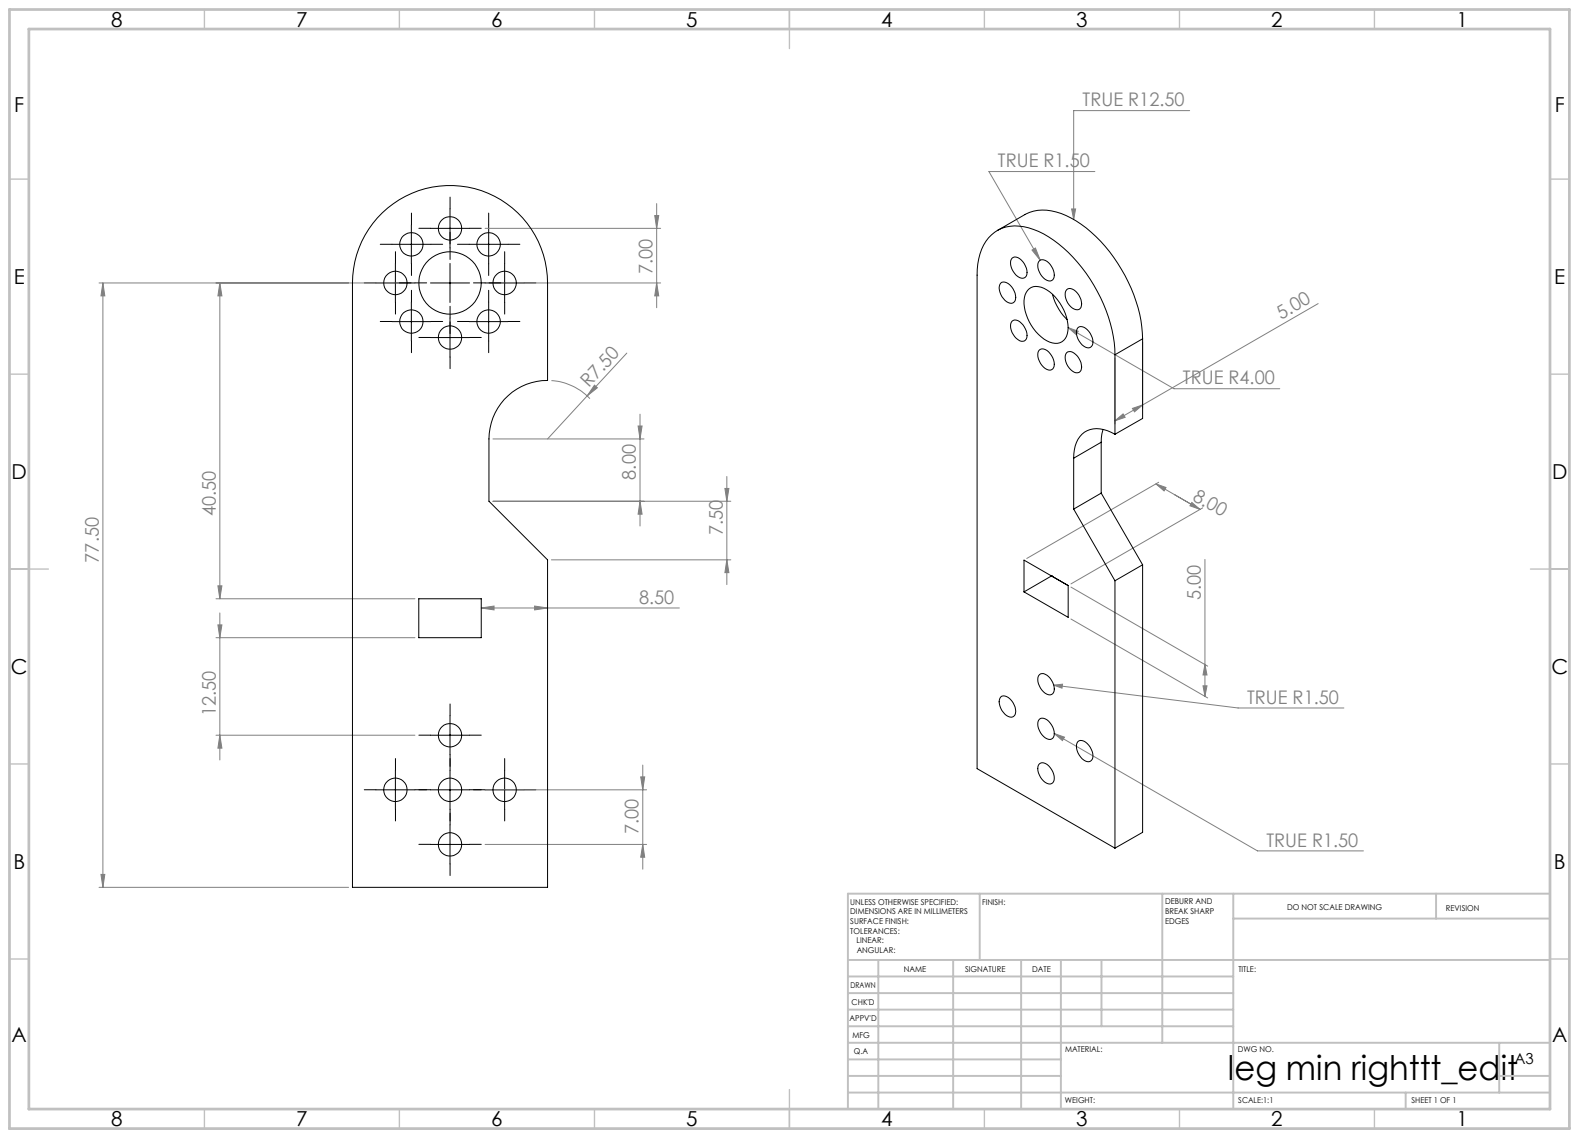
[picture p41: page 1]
TRUE R4.00; TRUE R1.50; TRUE R12.50; FINISH:; DEBURR AND; BREAK SHARP; DO NOT SCALE DRAWING; REVISION; SCALE:1:1; SHEET 1 OF 1

UNLESS OTHERWISE SPECIFIED:
DIMENSIONS ARE IN MILLIMETERS
SURFACE FINISH:
TOLERANCES:
LINEAR:
ANGULAR:

NAME | SIGNATURE | DATE | | | | TITLE:

DRAWN
CHK'D
APPV'D
MFG
Q.A | | | | MATERIAL: leg min righttt_edit | DWG NO. | A3

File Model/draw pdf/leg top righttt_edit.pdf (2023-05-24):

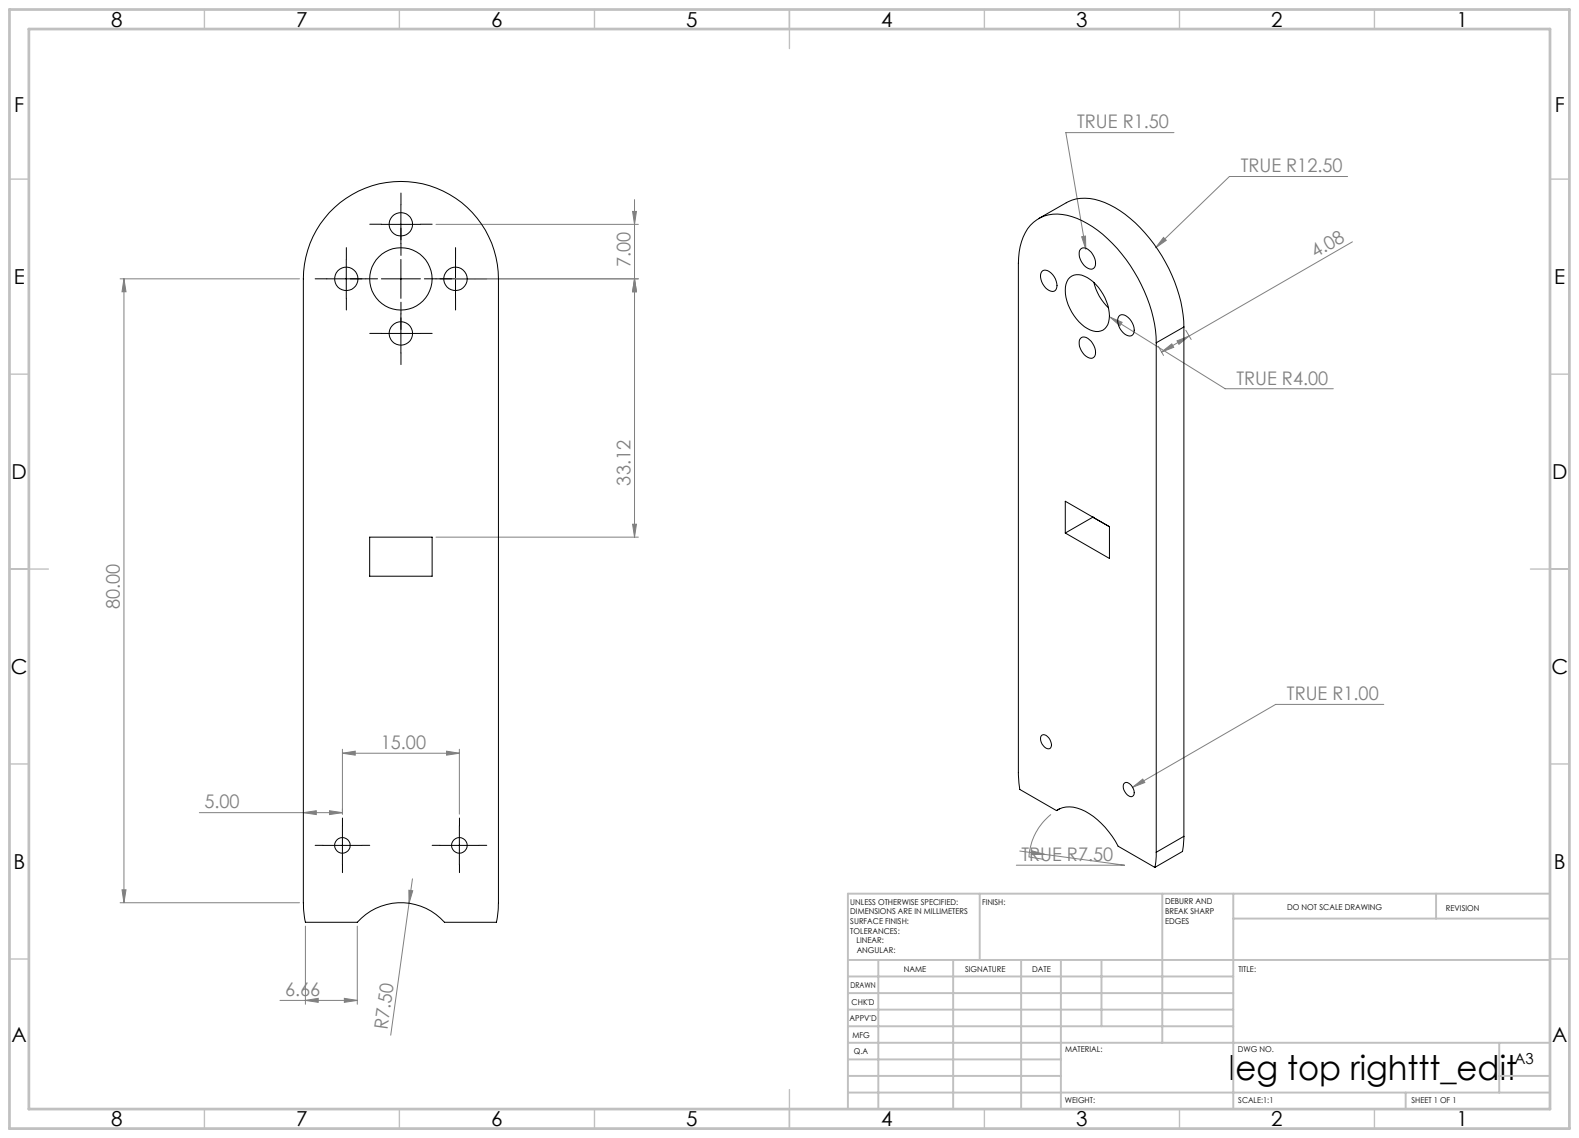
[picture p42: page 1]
TRUE R1.50; TRUE R4.00; TRUE R12.50; TRUE R1.00; TRUE R7.50; FINISH:; DEBURR AND; BREAK SHARP; DO NOT SCALE DRAWING; REVISION; SCALE:1:1; SHEET 1 OF 1

UNLESS OTHERWISE SPECIFIED:
DIMENSIONS ARE IN MILLIMETERS
SURFACE FINISH:
TOLERANCES:
LINEAR:
ANGULAR:

NAME | SIGNATURE | DATE | | | | TITLE:

DRAWN
CHK'D
APPV'D
MFG
Q.A | | | | MATERIAL: leg top righttt_edit | DWG NO. | A3

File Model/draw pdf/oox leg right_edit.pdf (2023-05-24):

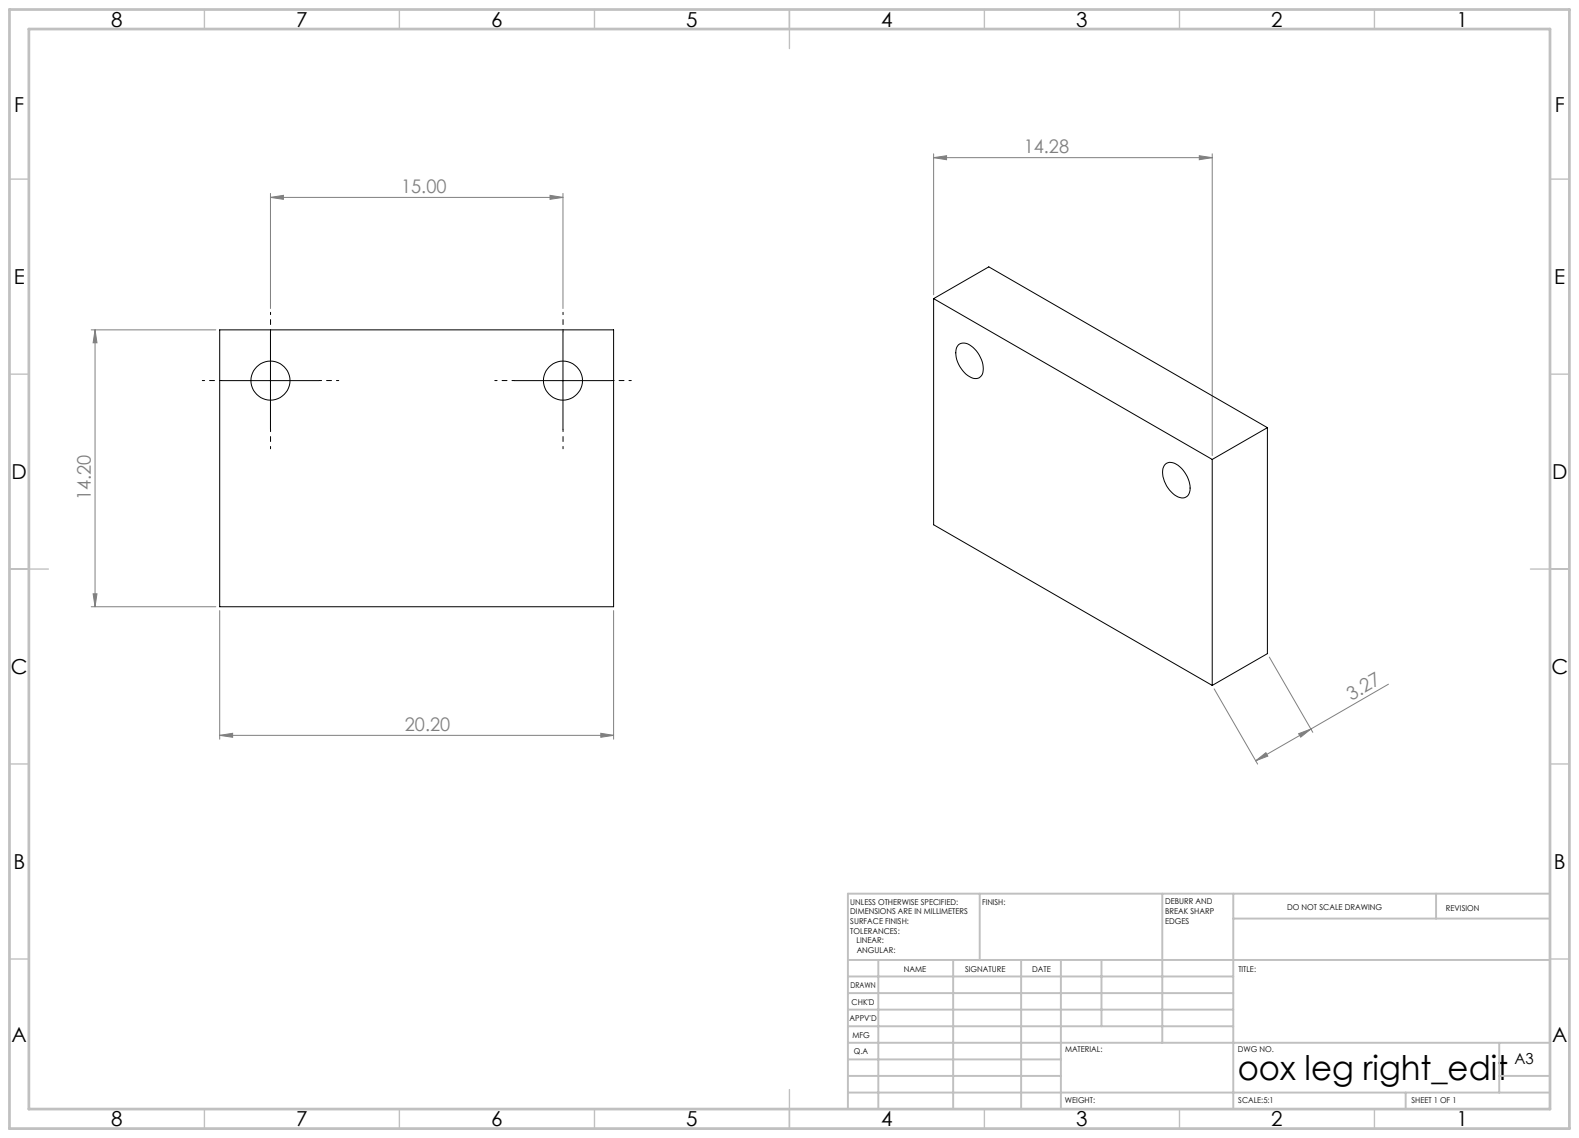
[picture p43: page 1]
FINISH:; DEBURR AND; BREAK SHARP; DO NOT SCALE DRAWING; REVISION; SCALE:5:1; SHEET 1 OF 1

UNLESS OTHERWISE SPECIFIED:
DIMENSIONS ARE IN MILLIMETERS
SURFACE FINISH:
TOLERANCES:
LINEAR:
ANGULAR:

NAME | SIGNATURE | DATE | | | | TITLE:

DRAWN
CHK'D
APPV'D
MFG
Q.A | | | | MATERIAL: | oox leg right_edit DWG NO. | A3

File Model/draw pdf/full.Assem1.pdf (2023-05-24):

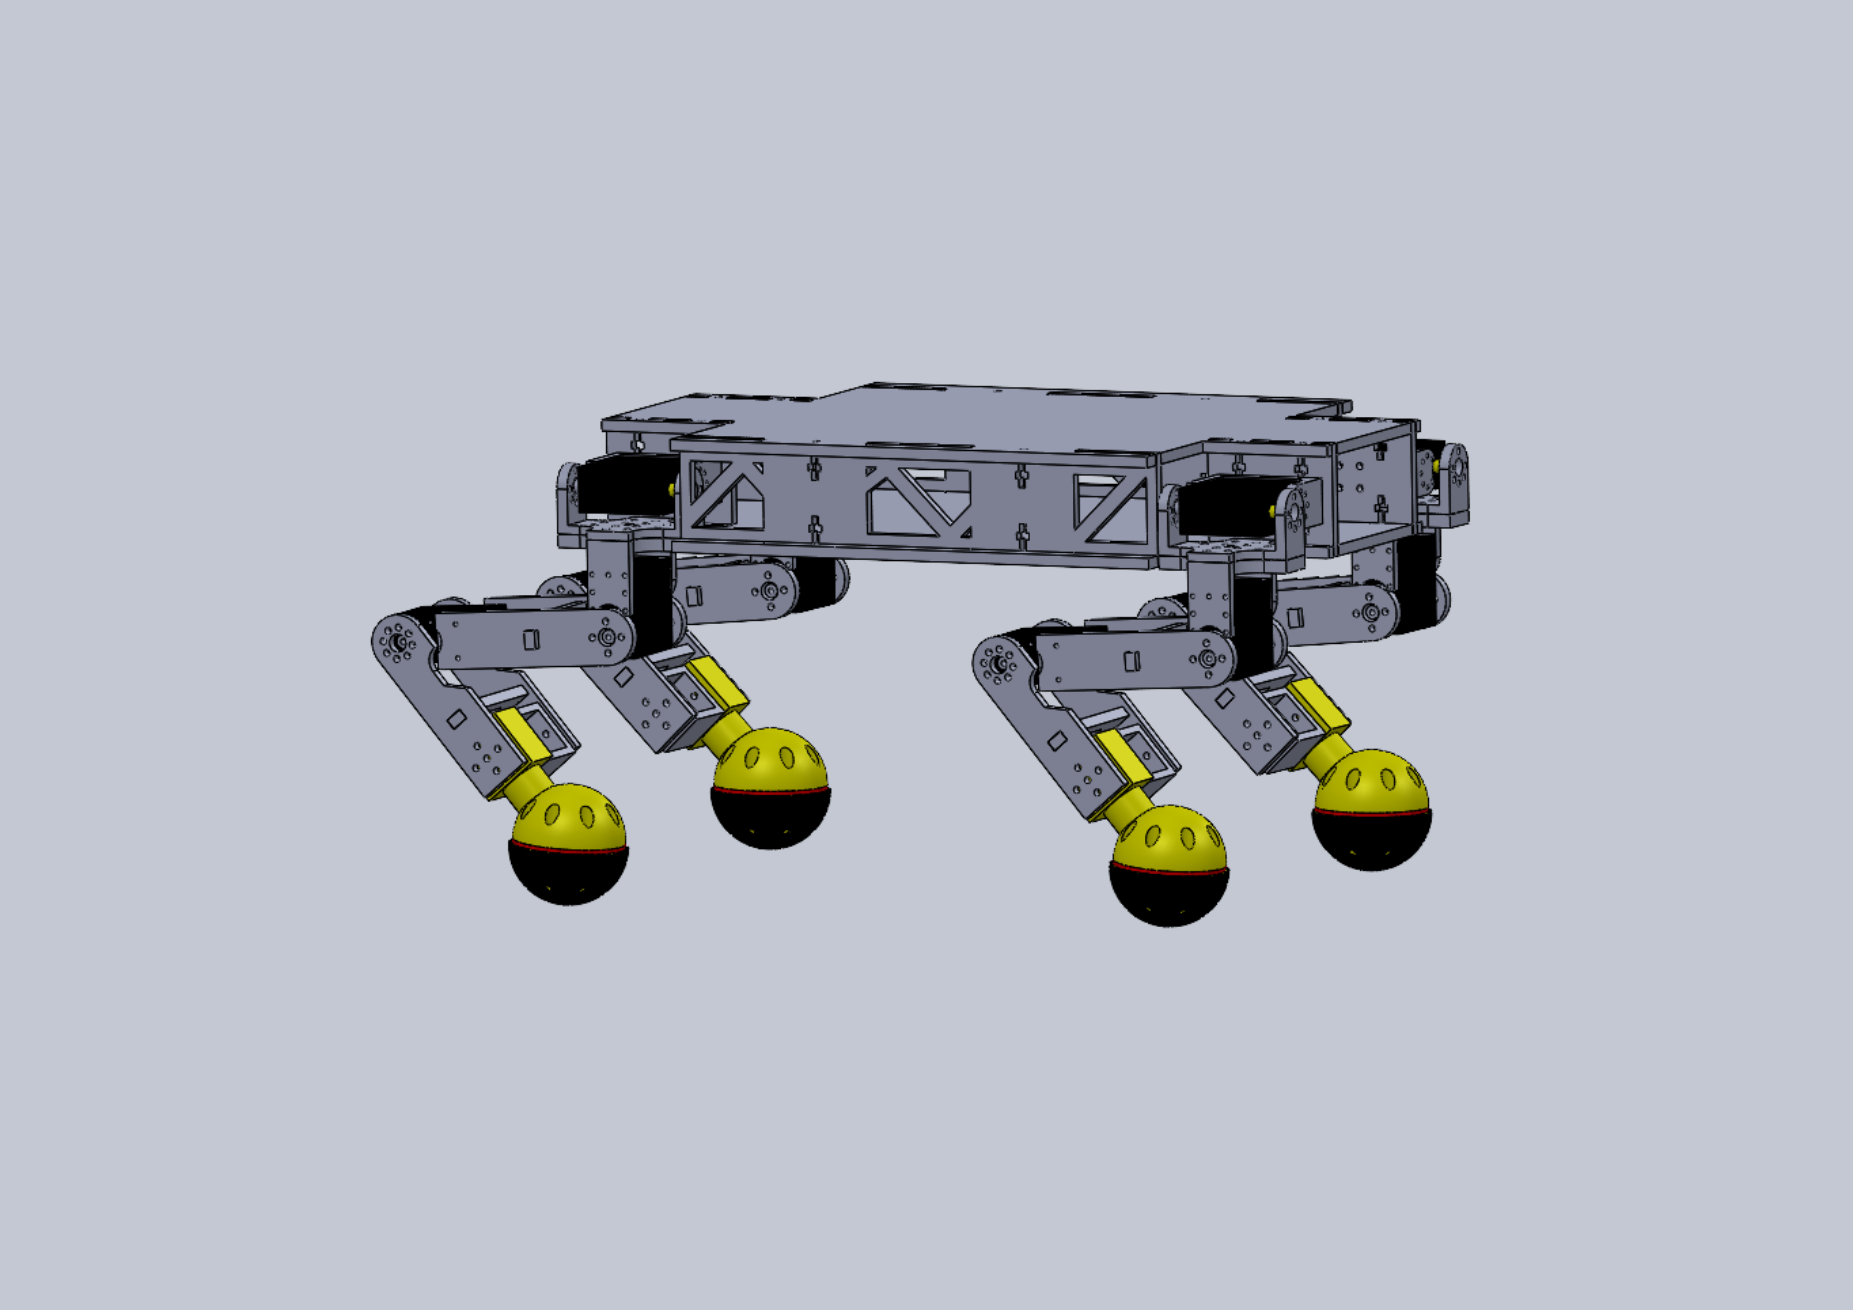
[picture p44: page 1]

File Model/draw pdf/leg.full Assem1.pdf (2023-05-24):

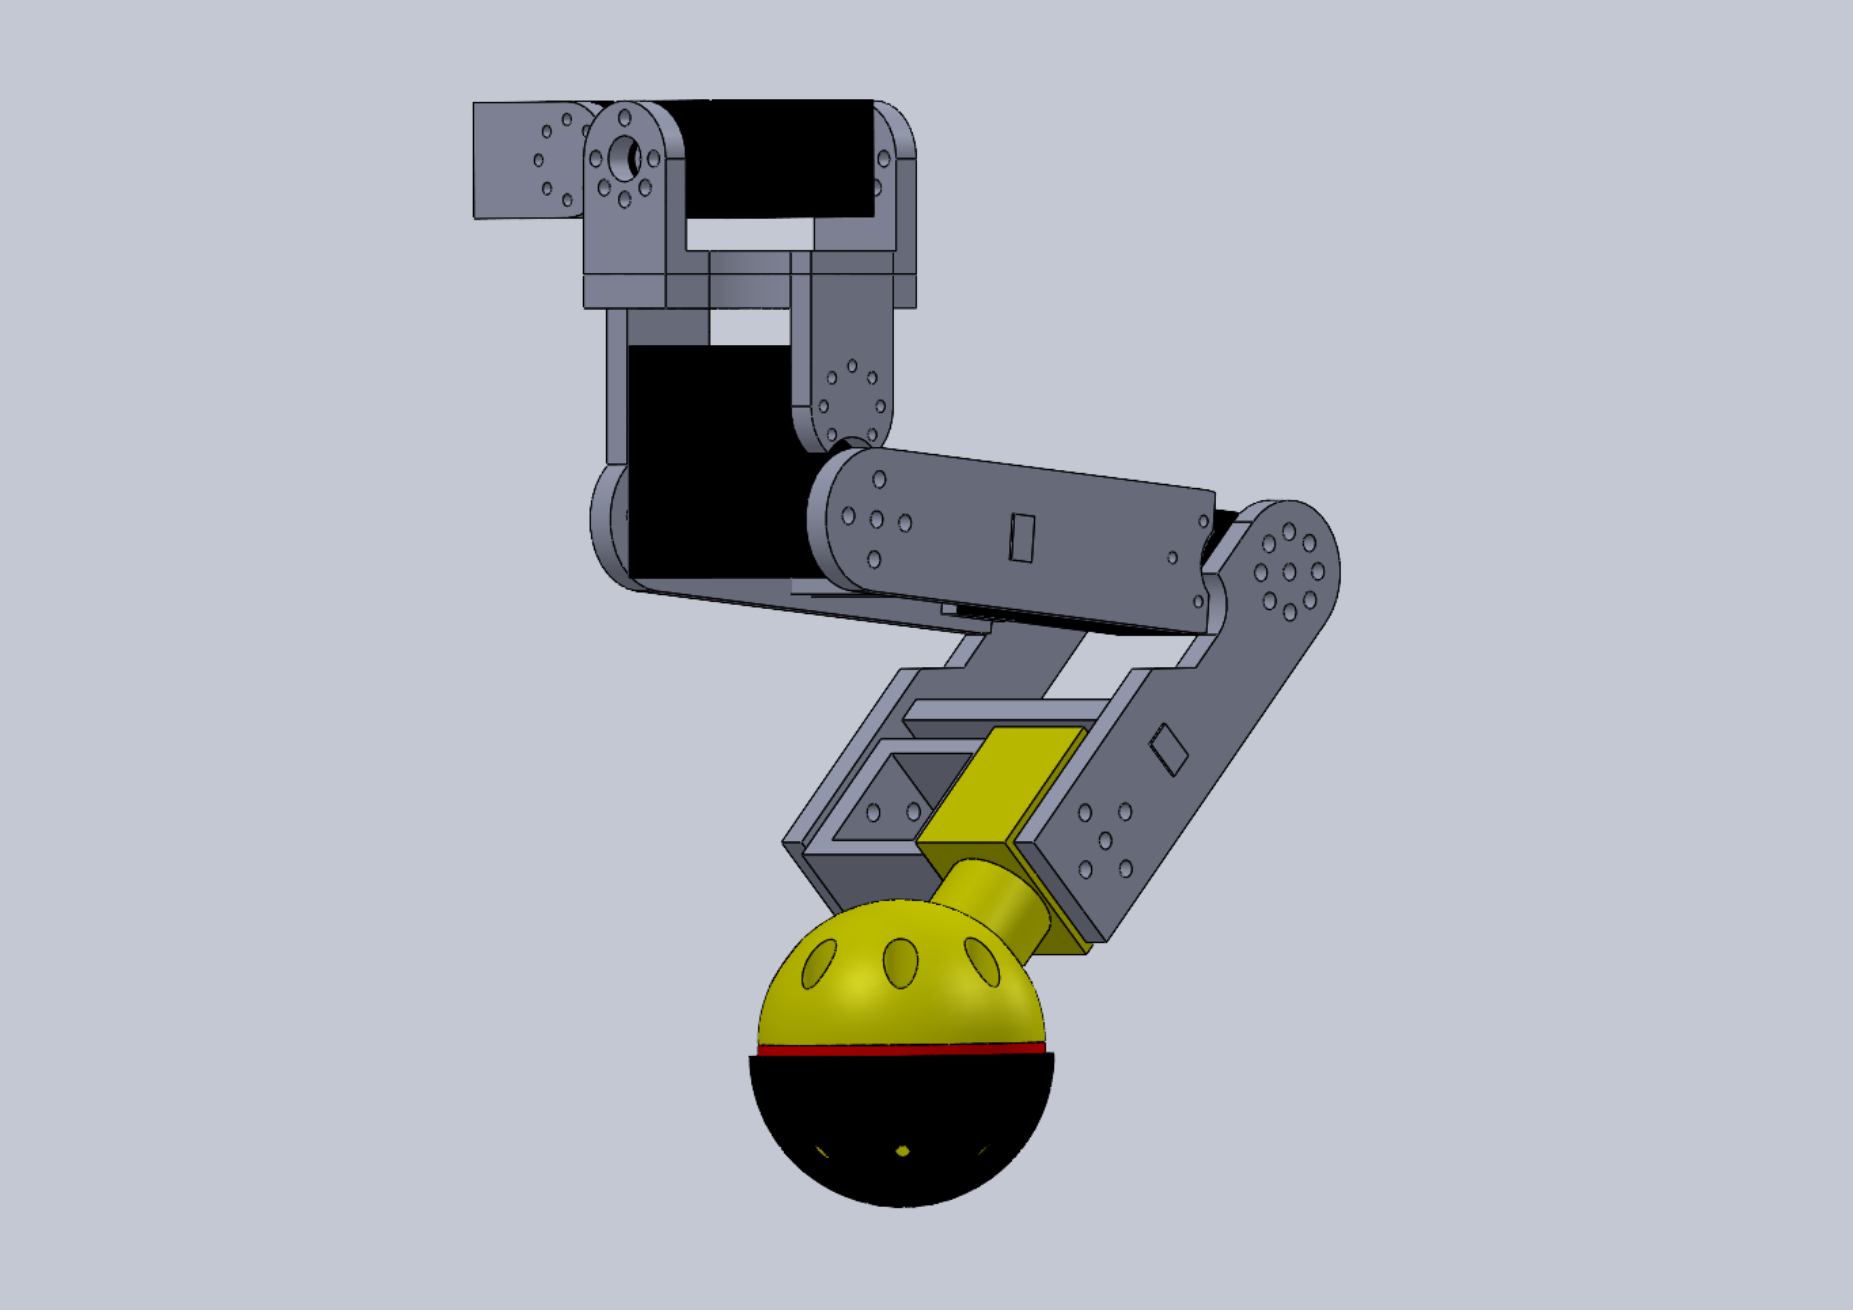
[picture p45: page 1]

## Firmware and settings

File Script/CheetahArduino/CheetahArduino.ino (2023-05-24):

#include <SCServo.h>

#define BUFFER_SIZE 40
//-------------------------------------------------------------
//MOTOR parameter
SCSCL sc;
//                           FR    BR    FL    BL
    /*1*/int Pos[13] = { 0,  15,    419,  400,  15,
                             649,  649,  215,  215,
                             0,    0,    434,  434
                        };
    int StayPos[13] = { 0,  15,    419,  400,  15,
                            700,  535,  300,  264,
                            200,  250,  200,  200
                        };
    //Feedback Position
    int FeedPos[13] =  { 0,  0,    434,  434,  0,
                             649,  649,  215,  215,
                             0,    0,    434,  434
                      };
    //Current Knee
    double FeedLoad[5]  = {
                         0,   0,    0,    0,    0
                      };     
//-------------------------------------------------------------

unsigned long PrevTime =0;
unsigned long Interval =25;
unsigned long currentTime;

unsigned char State_Serial =0;
unsigned char State_Data =0;
unsigned char Len =0;
unsigned char buff_data[BUFFER_SIZE];


void setup() {
  Serial1.begin(1000000); //communication to motor SCS
  Serial2.begin(921600); //commuication to notebook python ,max bus 921600
  Serial.begin(115200);//display data in arduino
  sc.pSerial = &Serial1;
//reset position
  pinMode(LED_BUILTIN, OUTPUT);
  for(int i = 1;i <= 12;i++){
    sc.RegWritePos(i,Pos[i], 0, 300);
  }
  sc.RegWriteAction();
  delay(749);
  for(int i = 1;i <= 12;i++){
    Pos[i] = StayPos[i];
    sc.RegWritePos(i,StayPos[i], 0, 300);
  }
  sc.RegWriteAction();
  delay(749);
  PrevTime = millis(); // Start Timer
//reset position
}
void byteUpdate(){
  Serial2.write(0xFF);//1
  Serial2.write(0xFF);//2
  unsigned int data_buffer = 0;
  unsigned int buffer_H;
  unsigned int buffer_L;
  Serial2.write(0x19);//3 Len
  unsigned char sum = 0x19;//0+Len
  for(int i = 5;i<=12;i++){
    data_buffer = FeedPos[i];
    buffer_H = data_buffer >> 8;//shift bit
    buffer_L = data_buffer & 0xFF;
    sum += buffer_H;
    sum += buffer_L;
    //2 byte per data
    Serial2.write(buffer_H);//byte1
    Serial2.write(buffer_L);//byte2
  }
  for(int i = 1;i<=4;i++){
    data_buffer = FeedLoad[i];
    buffer_H = data_buffer >> 8;//shift bit
    buffer_L = data_buffer & 0xFF;
    sum += buffer_H;
    sum += buffer_L;
    //2 byte per data
    Serial2.write(buffer_H);//byte1
    Serial2.write(buffer_L);//byte2
  }
  sum = sum & 0xff;
  Serial2.write(sum);
}
unsigned int count = 0;
void loop() {
  // put your main code here, to run repeatedly:

  static unsigned char index =0;

  
  if(Serial2.available() > 0) {
      switch(State_Serial){
        case 0:
          if (Serial2.read() == 0xFF){
             State_Serial++;
          }
          break;

        case 1:
          if(Serial2.read() == 0xFF)
          State_Serial++;
          Len=0;
          break;

        case 2:
          Len = Serial2.read();
          State_Serial++;
          index=0;
          break;

        case 3:
        //Len-1 = range data ["0-255" x 16] >> 4 Position Hip, 4 Position Knee
        //Loop = Len 
          if(index < (Len-1)){ //fetch data to buff_data
            buff_data[index] = Serial2.read();
            index++;
          }
          else{
            index = 0;
            State_Serial++;
          }
          break;

        case 4:
          unsigned char sum = Len;
          for(int i=0;i<Len;i++){
            sum += buff_data[i];
          }
          
          if(sum == Serial2.read()){
            State_Data = 1;
          
          }else{
            State_Data = 0;
            // Serial.println("sum != 0");
          }
          State_Serial=0; 
          break;

      }
  }

  currentTime = millis();
  if(currentTime-PrevTime > Interval){
    if(State_Data == 1){
      State_Data = 0;
      unsigned int hip_FR = buff_data[0];
      hip_FR = hip_FR<<8;
      hip_FR += buff_data[1];
      unsigned int hip_BR = buff_data[2];
      hip_BR = hip_BR<<8;
      hip_BR += buff_data[3];
      unsigned int hip_FL = buff_data[4];
      hip_FL = hip_FL<<8;
      hip_FL += buff_data[5];
      unsigned int hip_BL = buff_data[6];
      hip_BL = hip_BL<<8;
      hip_BL += buff_data[7];
      unsigned int knee_FR = buff_data[8];
      knee_FR = knee_FR<<8;
      knee_FR += buff_data[9];
      unsigned int knee_BR = buff_data[10];
      knee_BR = knee_BR<<8;
      knee_BR += buff_data[11];
      unsigned int knee_FL = buff_data[12];
      knee_FL = knee_FL<<8;
      knee_FL += buff_data[13];
      unsigned int knee_BL = buff_data[14];
      knee_BL = knee_BL<<8;
      knee_BL += buff_data[15]
      //Update Position Hip
      Pos[5]  = hip_FR;
      Pos[6]  = hip_BR;
      Pos[7]  = hip_FL;
      Pos[8]  = hip_BL;
      //Update Position Knee
      Pos[9]  = knee_FR;
      Pos[10] = knee_BR;
      Pos[11] = knee_FL;
      Pos[12] = knee_BL;

      String txt  = "";
      int Pos_Feed = 0;
      int Load_Feed = 0;
        sc.RegWritePos(1,Pos[1], 0, 700);
        sc.RegWritePos(2,Pos[2], 0, 700);
        sc.RegWritePos(3,Pos[3], 0, 700);
        sc.RegWritePos(4,Pos[4], 0, 700);
        sc.RegWriteAction();
          for(int i = 5;i <= 12;i++){
            //Move Position Hip and Knee
            sc.WritePos(i, Pos[i] , 0,700);
            Pos_Feed = sc.ReadPos(i);
            if(i >= 5 && i <= 8){
              Load_Feed = sc.ReadLoad(i);
              if(Load_Feed <0){
                Load_Feed =0;
              }
              FeedLoad[i-4] = abs(Load_Feed);
            }
            FeedPos[i] = Pos_Feed;
            // txt += String(Pos[i]);
          }
      }// end if state 0
      byteUpdate();
      PrevTime = millis();
      Serial.println(1);
    }
}

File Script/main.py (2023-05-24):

import serial
import time
import controlLeg as cL
import numpy as np
import pandas as pd
serialcomm = serial.Serial('COM12', 921600)
serialcomm.timeout = 1
#           FR    BR    FL    BL
Pos = [0,   0,    434,  434,  0,
            700,  535,  300,  264,
            200,  250,  200,  200   ]
# 1 = FR,2 = BR,3 = FL,4 = BL
# RangePos = [[0,0],
#             [[215,800],[0,434]],
#             [[215,800],[0,434]],
#             [[0,649],[434,0]],
#             [[0,649],[434,0]]]
RangePos = [[0,0],
            [[468,658],[100,370]],
            [[468,685],[100,370]],
            [[400,180],[334,64]],
            [[400,156],[334,64]]]
Database = {"O1FR": [],"O2FR": [],"O1BL": [],"O2BL": [],"O1FL": [],"O2FL": [],"O1BR": [],"O2BR": [],"gFR1":[],"gFR2":[],"fFR1":[],"fFR2":[]}
ID = [0,1,2,3,4]
O_FR  = np.zeros((2,50))
O_BR  = np.zeros((2,50))
O_FL  = np.zeros((2,50))
O_BL  = np.zeros((2,50))
Tpeak = [0,0,0,0]
time_stack = [0] * 50
FR = cL.ControlLegRobot(ID[1],[Pos[5],Pos[9]], RangePos[ID[1]],"FR")
BR = cL.ControlLegRobot(ID[2],[Pos[6],Pos[10]],RangePos[ID[2]],"BR")
FL = cL.ControlLegRobot(ID[3],[Pos[7],Pos[11]],RangePos[ID[3]],"FL")
BL = cL.ControlLegRobot(ID[4],[Pos[8],Pos[12]],RangePos[ID[4]],"BL")

print(str(FR.RegisterID()))
print(str(BR.RegisterID()))
print(str(FL.RegisterID()))
print(str(BL.RegisterID()))

time_feedback = 0
current_feedback = [0,0,0,0]
pos_hip          = [0,0,0,0]
pos_knee         = [0,0,0,0]
res_pos          = [[0,0,0,0],[0,0,0,0]]
ESP_stack = bytearray()
def byteSend(hip,knee):
    packet = bytearray()
    packet.append(0xFF)
    packet.append(0xFF)
    packet.append(0x11)
    for i in range(4):
        dataH = hip[i] >> 8
        dataL = hip[i] & 0XFF
        packet.append(dataH)
        packet.append(dataL)
    for i in range(4):
        dataH = knee[i] >> 8
        dataL = knee[i] & 0XFF
        packet.append(dataH)
        packet.append(dataL)
    check_sum = sum(packet[2:])
    
    packet.append(check_sum &0xff)
    serialcomm.write(packet)

def main():
    global O_FR,O_BR,O_FL,O_BL,Tpeak,time_stack,time_feedback,ESP_stack,pos_hip,pos_knee,current_feedback,res_pos,Pos
    state_res = "start"
    if(state_res == "start"):
        print("Start Task")
        #test loop
        State_py = 0
        index = 0
        # byte
        Len = 0
        sum_data = 0
        State_Cal = 0
        start_time = time.time()
        count = 0
        # for i in range(100):
        while(True):
            end_time = time.time()                                                                          #   time :     hip   :    knee   :  current
            ESP_Req = serialcomm.read(1)
            if State_py == 0:   
                if ESP_Req ==  b'\xff' :
                    sum_data = 0
                    Len = 0
                    State_py = 1
            elif State_py == 1 :
                if ESP_Req ==  b'\xff' :
                    State_py = 2
                else:
                    State_py = 0
            elif State_py == 2:
                Len = int.from_bytes(ESP_Req, byteorder='big', signed=False)
                State_py = 3
                index = 0
            elif State_py == 3:
                if index < Len-1:
                    ESP_stack.append(int.from_bytes(ESP_Req, byteorder='big', signed=False))
                    index += 1
                else :
                    sum_data = int.from_bytes(ESP_Req, byteorder='big', signed=False)
                    index = 0
                    State_py = 4
                
            elif State_py == 4:  
                        
                check_sum = Len+sum(ESP_stack)
                check_sum = check_sum &0xff   
                if check_sum == sum_data and ESP_stack != b'':
                    State_py = 5
                    Len = 0
                else :
                    ESP_stack = bytearray()
                    State_py = 0
                    Len = 0
            elif State_py == 5:

                hip_FR = ESP_stack[0]
                hip_FR = hip_FR<<8
                hip_FR += ESP_stack[1]
                hip_BR = ESP_stack[2]
                hip_BR = hip_BR<<8
                hip_BR += ESP_stack[3]
                hip_FL = ESP_stack[4]
                hip_FL = hip_FL<<8
                hip_FL += ESP_stack[5]
                hip_BL = ESP_stack[6]
                hip_BL = hip_BL<<8
                hip_BL += ESP_stack[7]

                knee_FR = ESP_stack[8]
                knee_FR = knee_FR<<8
                knee_FR += ESP_stack[9]
                knee_BR = ESP_stack[10]
                knee_BR = knee_BR<<8
                knee_BR += ESP_stack[11]
                knee_FL = ESP_stack[12]
                knee_FL = knee_FL<<8
                knee_FL += ESP_stack[13]
                knee_BL = ESP_stack[14]
                knee_BL = knee_BL<<8
                knee_BL += ESP_stack[15]
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
